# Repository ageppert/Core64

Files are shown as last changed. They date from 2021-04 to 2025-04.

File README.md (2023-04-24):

# Core64 and Core64c
Official Core64 and Core64c Interactive Core Memory Badge Kit Firmware and Documentation!

Weave your own 64 bits of core memory over the top of LEDs to interact with directly using a magnetic wand.



Purchase or get support: https://www.Core64.io

Follow this project's origin story at: https://hackaday.io/project/166155-core-64-interactive-core-memory-badge

This repository supports the Core64 and Core64c kits starting with the Beta Kit (Hardware Version 0.5.0).

See latest firmware release at https://github.com/ageppert/Core64/releases (pre-compiled firmware for Teensy 3.2 and Pico-based versions)

# Hardware Version History (latest on top)

Core64 V0.8 Pico-based Kit:

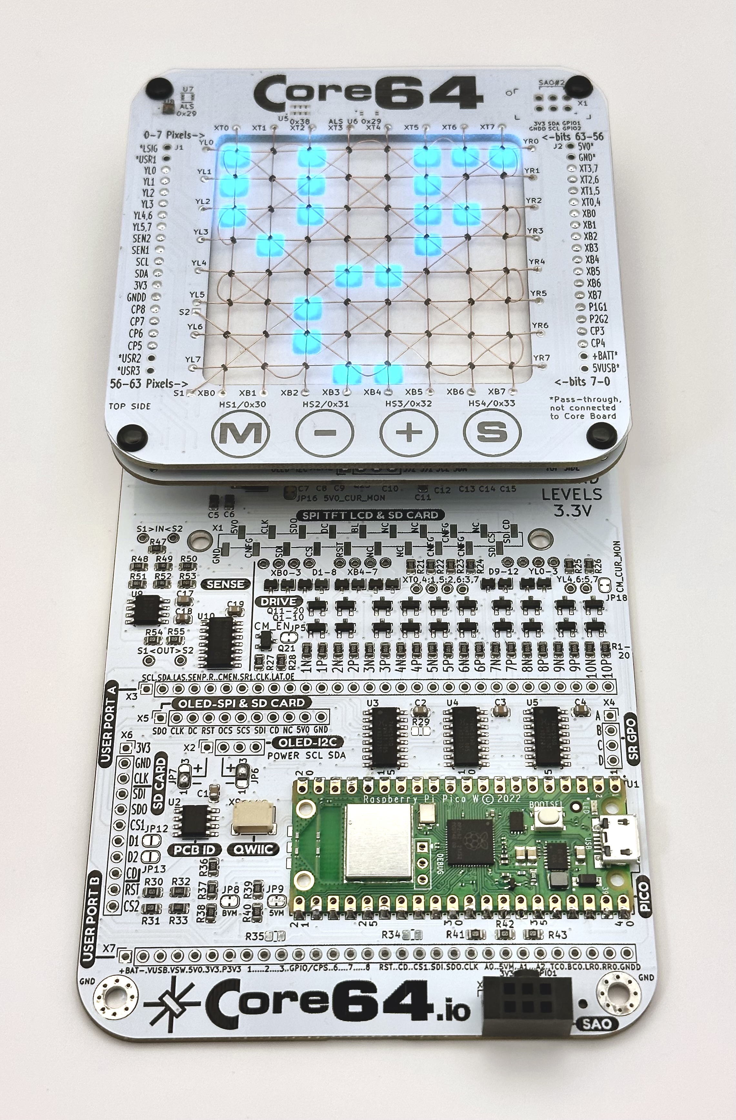
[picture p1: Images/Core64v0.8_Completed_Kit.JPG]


Core64c V0.4 Pico-based Kit:

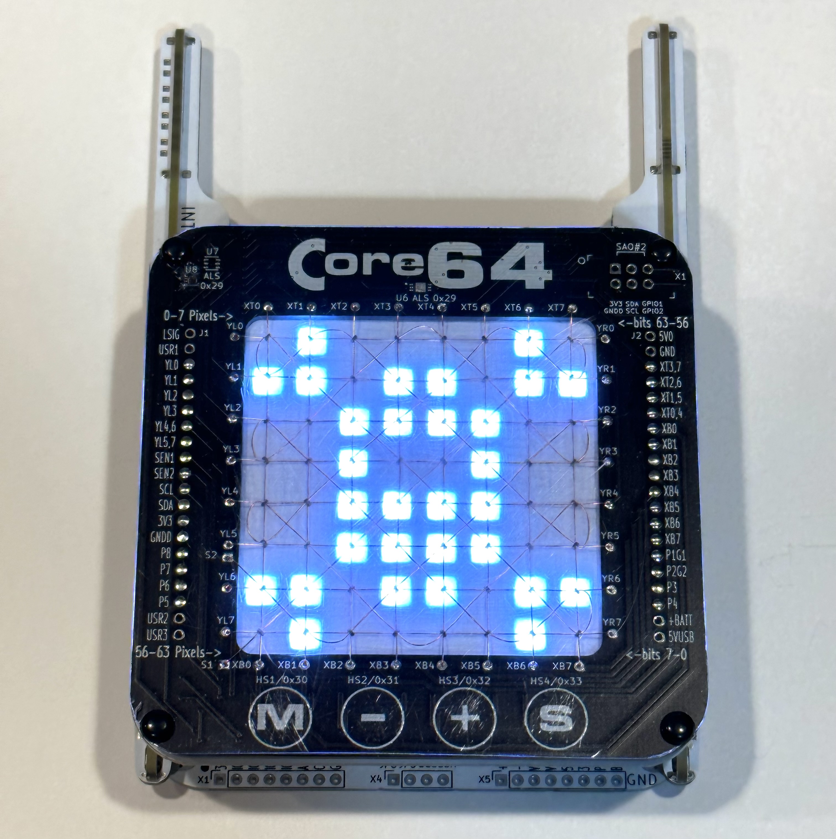
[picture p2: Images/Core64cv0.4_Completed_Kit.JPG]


Core64 V0.6 Pre-Production Teensy 3.2-based Kits. Associated Firmware Release https://github.com/ageppert/Core64/releases/tag/V0.6.3

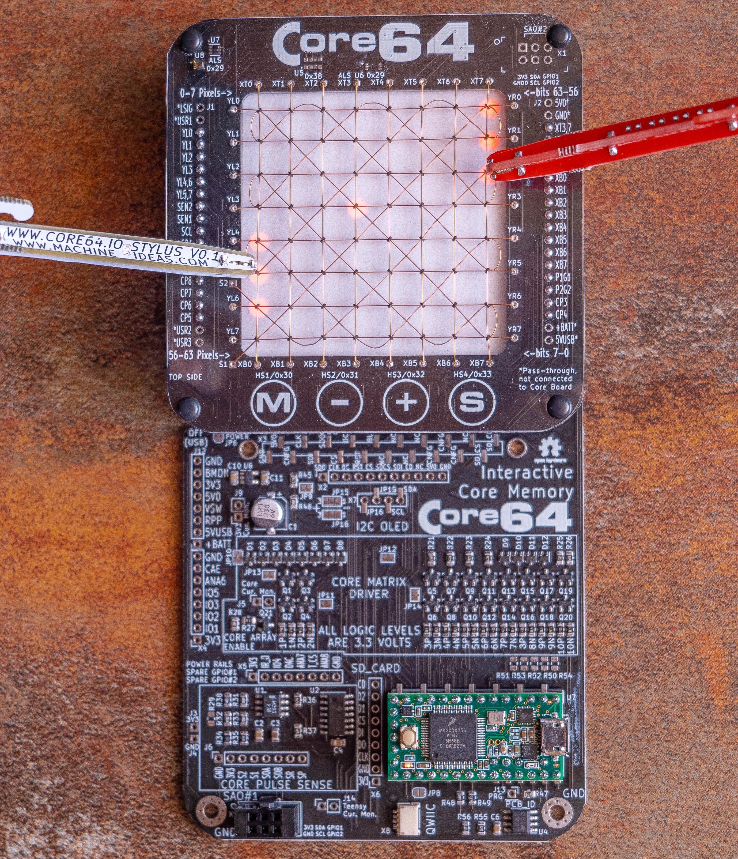
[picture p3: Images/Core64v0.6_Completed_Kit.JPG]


Core64 V0.5 Beta Test Kits Teensy 3.2-based. Associated Firmware Release https://github.com/ageppert/Core64/releases/tag/V0.5-Beta-Kit-Release-Demo

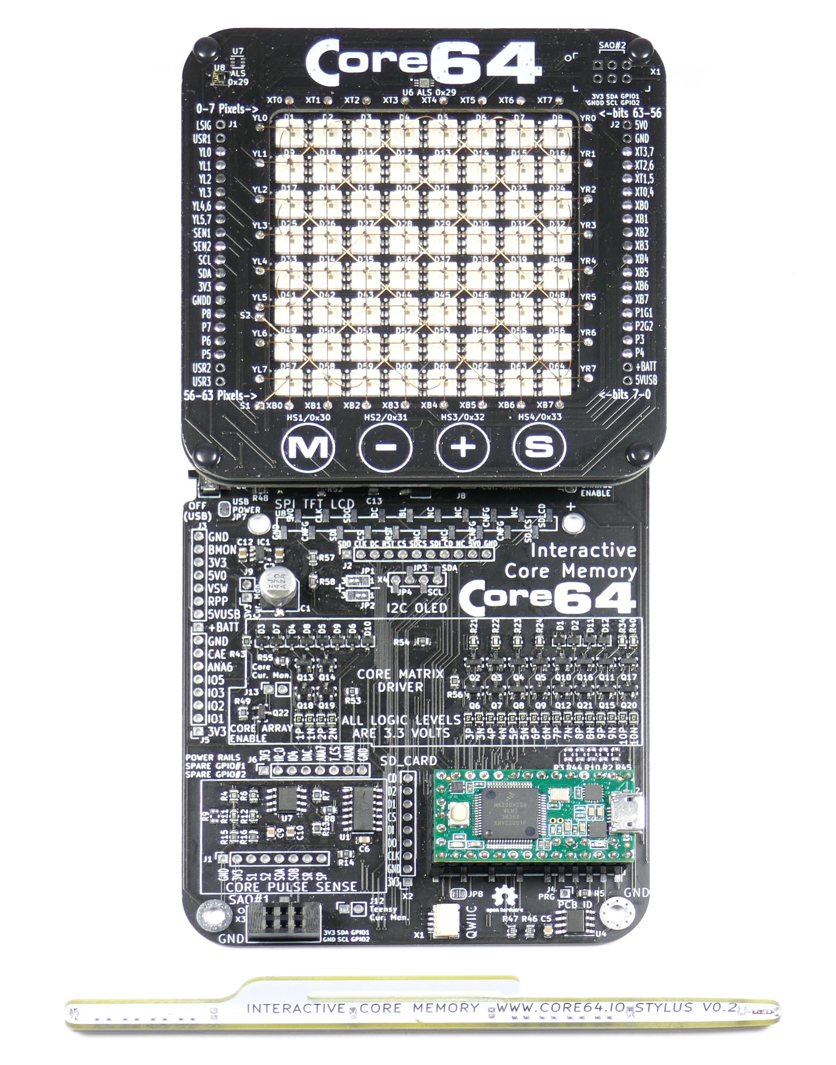
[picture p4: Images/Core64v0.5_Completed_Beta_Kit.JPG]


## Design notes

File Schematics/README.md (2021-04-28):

# Schematics

LB = Logic Board

CB = Core Board

LM = LED Matrix

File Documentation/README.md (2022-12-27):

# Core64 and Core64c
This directory contains all of the official Core64 and Core64c Interactive Core Memory Badge Kit Documentation.

You can view the files directly from your web browser, or download them to print out.

ASSEMBLY GUIDE: Start here. This covers the entire assembly process for the standard configuration of the kit. (This was previously hosted on GitBook, but the documents in this directory supersedes the information in Gitbook.)

FIRMWARE UPDATE GUIDE: After assembly is completed, you will be guided through the steps to install/update to the latest firmware.

QUICK START GUIDE: After the Core64 kit is working, you can jump to this guide to explore the basic operating modes.

TROUBLESHOOTING GUIDE: If the kit is not working correctly after the firmware has been updated, this guide will cover automated and manual troubleshooting techniques.

USER GUIDE: After you have the firmware installed and running, the User Guide will describe how to use the completed Core64 kit with all of it's standard functionality. There are also sections describing some simple upgrades you may want to perform, such as a different battery and display screens.

HACKER GUIDE: I know seeing "hacker" and "guide" together are the definition of an oxymoron... but this guide serves as a launching point for all sorts of hacking that you can do with this kit. The guide starts with all of the details about how the core memory and the standard features work. If covers the electronics in detail and touches on the concepts present in the firmware. It then offers up open-ended hacks and ideas that you can pursue. If you want to go deeper with the firmware, the PROGRAMMERS REFERENCE GUIDE is the place to go.

PROGRAMMERS REFERENCE GUIDE: If you want to modify or create your own firmware, this is the place to start! This guide starts with how to set up the development environment. It goes into detail regarding the architecture, file organization, and details of implementation.

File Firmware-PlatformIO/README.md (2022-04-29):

# Firmware Source Code
This sub-directory supports Core64 HWV0.4+ and Core64c HWV0.2+.

THis sub-directory supports firmware starting at FWV 0.7.0 using the PlatformIO environment in VSCode.

See the "Firmware" sub-directory for the older Arduino IDE firmware source code.

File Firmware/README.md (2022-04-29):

# Firmware Source Code
This sub-directory supports Core64 into HWV0.5.

This firmware (up to FWV0.6.3) is compatible with the Arduino IDE.

Firmware after FWV0.6.3, starting at FWV 0.7.0, moves to the PlatformIO environment in VSCode.

See the Firmware-PlatformIO sub-directory for that firmware source code.

Arduino project folder, sketches, libraries.

This firmware was used for development of Core64 V0.5 and beyond.

This firmware is also compatible with Core64c V0.2 and beyond.

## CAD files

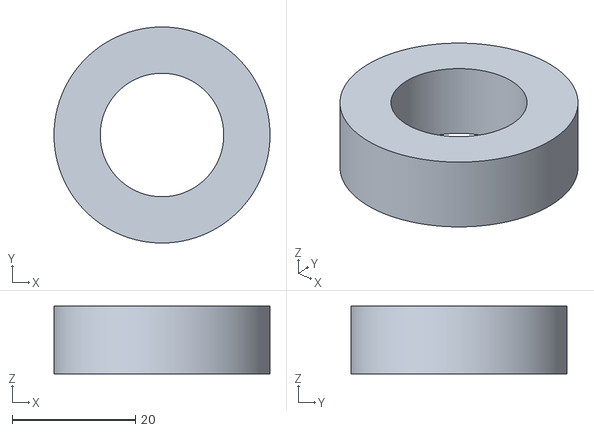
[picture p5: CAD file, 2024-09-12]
Mechanical/Core Memory Demo - Large Plastic Core.stl
35.0 x 35.0 x 11.0

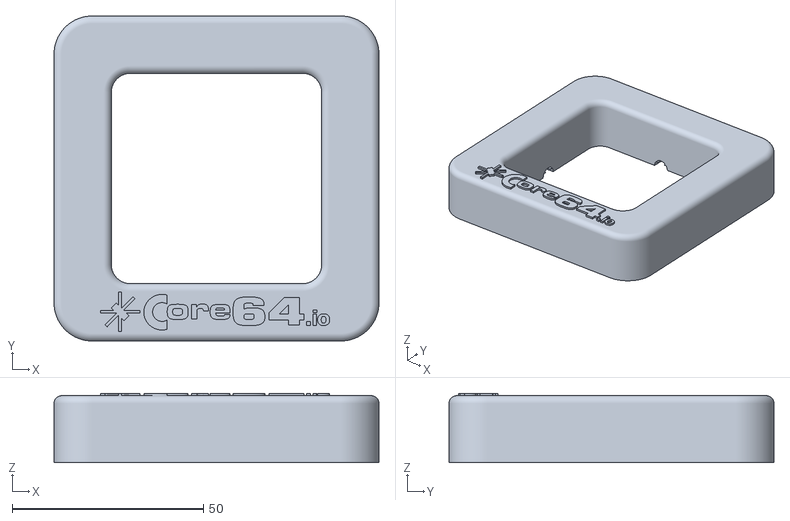
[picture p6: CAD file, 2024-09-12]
Mechanical/Core Memory Demo Frame - TOP.stl
85.0 x 85.0 x 18.1

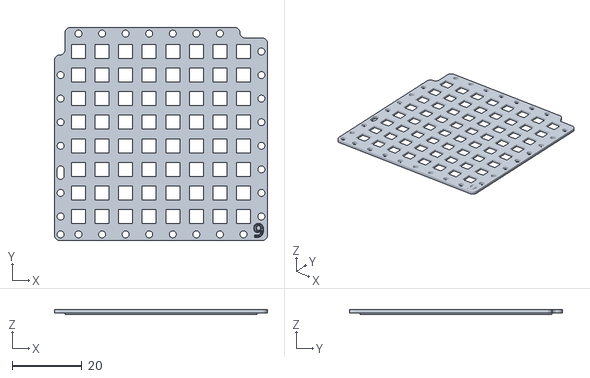
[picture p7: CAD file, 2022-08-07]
Mechanical/Diffuser Grid V0.9 Square 6.75mm centers.stl
61.0 x 61.0 x 1.40

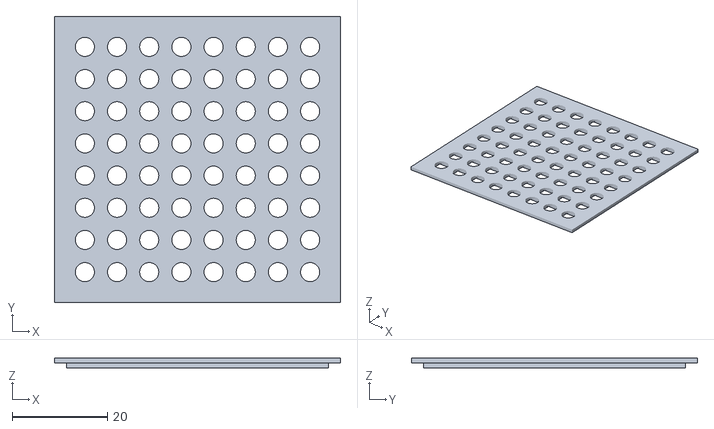
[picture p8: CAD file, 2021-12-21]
Mechanical/Diffuser Grid V0.2 Round 4mm Pixel Holes.stl
60.0 x 60.0 x 2.00

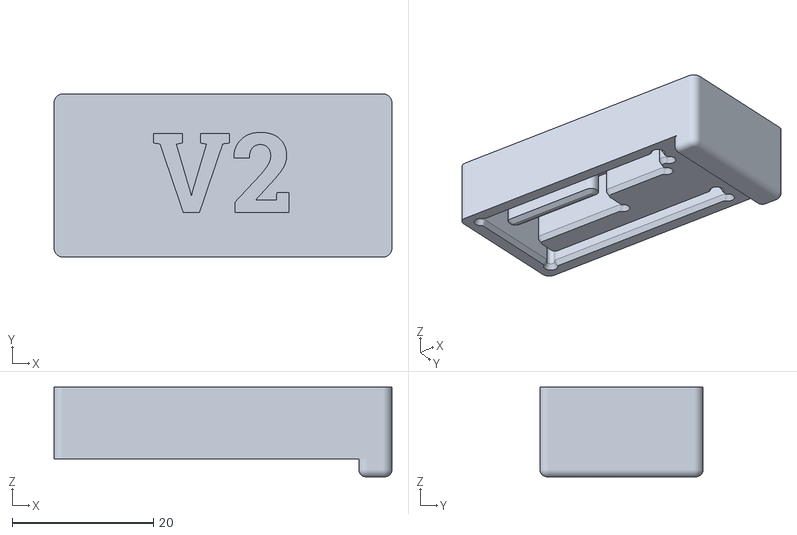
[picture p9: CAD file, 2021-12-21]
Mechanical/Alignment Jig Sockets Teensy3.2 on LB V0.5-0.6 (V2).stl
47.9 x 23.1 x 12.7

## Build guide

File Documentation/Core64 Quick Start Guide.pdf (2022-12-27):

Core Memory Interactive Kit - Core64 - Quick Start Guide | Firmware V0.7.22 | 2022-12-20 | Andy Geppert | www.Core64.io | 1

# Core64 Interactive Core Memory Kit Quick Start User Guide

- Power Switch (Selects battery power or USB power, if connected)
- Magnetic Stylus (used for all interaction with Core Memory Matrix and Soft Buttons)
- 8x8 Core Memory Array (top layer) and RGB LED Matrix (bottom layer)
- Magnetic hall sensor buttons: (M) (+) (-) (S) are Mode, Increase, Decrease, Select

Power ON starts in demo mode. Move through demo modes with (+) and (-) using the Magnetic Stylus.

Touch Menu (M) with the Magnetic Stylus to enter the dGAUSS top level menu. Touch again to exit to last mode. Touch sub-menu letter on LED Matrix to enter the sub-menus:
d = Demos (Scrolling text through core memory, color symbols without core detection)
G = Games (Snake, Pong)
A = Applications (Monochrome drawing, touch (S) with Magnetic Stylus to clear the screen)
U = Utilities (Flux Detector)
S = Special (Binary counting bits, Pixel sequence test, EEPROM test, rainbow color, toggle one bit, read/write one bit, read/write all bits, test hall sensors)
S = Settings (empty)

Sub-menu name will appear for 3 seconds and automatically move to the first and next items in the sub-menu list. In the sub-menu, move through available choices with (+) and (–) magnetic buttons. Select the desired mode displayed on the LED Matrix with the (S) magnetic button.

After 30 seconds of no user interaction, mode will return to the default demo mode. Except for drawing mode, which does not time-out.

Like all of the other documentation guides, this one assumes you are working with the latest firmware.

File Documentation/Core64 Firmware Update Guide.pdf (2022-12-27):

.io

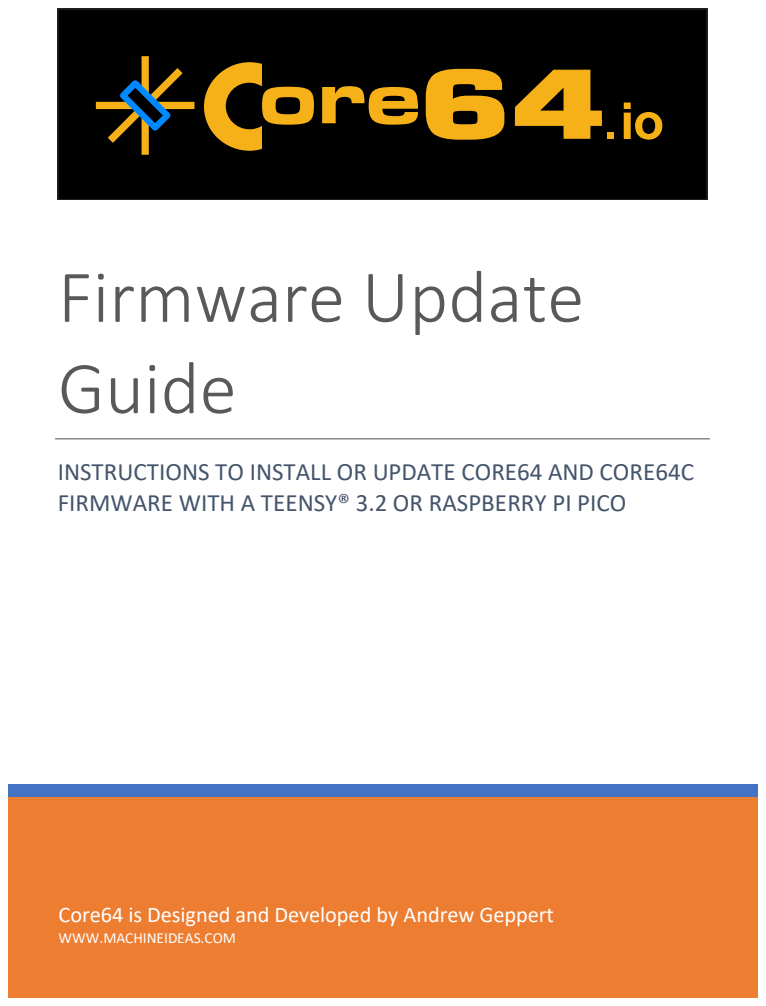
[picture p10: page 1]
Firmware Update Guide

INSTRUCTIONS TO INSTALL OR UPDATE CORE64 AND CORE64C
FIRMWARE WITH A TEENSY® 3.2 OR RASPBERRY PI PICO

Core64 is Designed and Developed by Andrew Geppert
WWW.MACHINEIDEAS.COM

Core64 Firmware Update Guide | www.Core64.io | 2

## 1. TABLE OF CONTENTS

The latest version of this and related Core64 guides are located at: https://github.com/ageppert/Core64/tree/master/Documentation

## 2. VERSION HISTORY OF THIS GUIDE

Revision | Description | Author | Date
A | First draft. | Andy Geppert | 2022-12-23

## 3. IMPORTANT CAUTIONS AND WARNINGS

Beware the ESD monster!

Sometimes the term “Core64” might refer generally to “Core64c” which is the compact version. Core64 is specifically the larger or full-size version.

Do not place the Core64 circuit boards directly on a metal surface.

⚠ These caution symbols point out important things to help ensure your assembly goes smoothly!

## 4. INTRODUCTION

This guide attempts to make the firmware update as simple as possible. If you’d like more detail so you can modify or create your own firmware for Core64, check out the Core64 Programmers Reference Guide.

Kits with the Raspberry Pi Pico (all Core64c kits, and Core64 V0.7+ kits) are not pre-programmed with firmware. However, the Pico is very easy to update because it does not need a special firmware loader. To program or update the Pico, simply drag-n-drop the firmware.uf2 file onto it when it is mounted on the computer’s desktop. For details, see section 5. Pico: Firmware Update.

The Teensy® 3.2 (used in early Core64 kits) is pre-programmed with firmware which will get you started with some basic functionality. Updating and programming the Teensy® requires a special firmware loader. A specific firmware upload tool is required for programming the Teensy® 3.2. It is developed and supported by PJRC, who are the makers of the Teensy® series of microcontroller boards. To update the Teensy® 3.2, you’ll need the Teensy® Loader. Details for installing the software and updating the Teensy® 3.2 are in Section 6. Teensy®: Firmware Update.

Please use the latest firmware. Some limited notes about older versions of the firmware are listed in the appendix, but those versions are incomplete and unsupported. And they aren’t as much fun as the latest firmware.

This guide assumes you have the Teensy® or Pico microcontroller installed on the Core64 Logic Board. They can also be programmed as a standalone device.

The next sections describe all the steps in detail. At the time of this writing, the instructions only cover Windows and Mac operating systems. If you are running Linux, I assume you can figure out how to adapt these instructions to your OS. And there are a lot of resources on the web to supplement these instructions if you get stuck.

## 5. PICO: FIRMWARE UPDATE

The firmware update process is very simple for the Pico. No installers are needed.

Step 1: Connect USB Cable
Connect the Pico to your computer with the MicroUSB data cable.

The Pico should now be mounted on the desktop as a USB mass storage device. If it does not show up, unplug it, then hold down the button on the Pico and plug in the USB cable, then release the button. This forces it into bootloader mode.

Step 2: Download Firmware
Download the latest firmware from https://github.com/ageppert/Core64/releases
Expand Assets and click on the “Core64_Pico_x.y.z_firmware.uf2” file to save it to your Downloads folder.

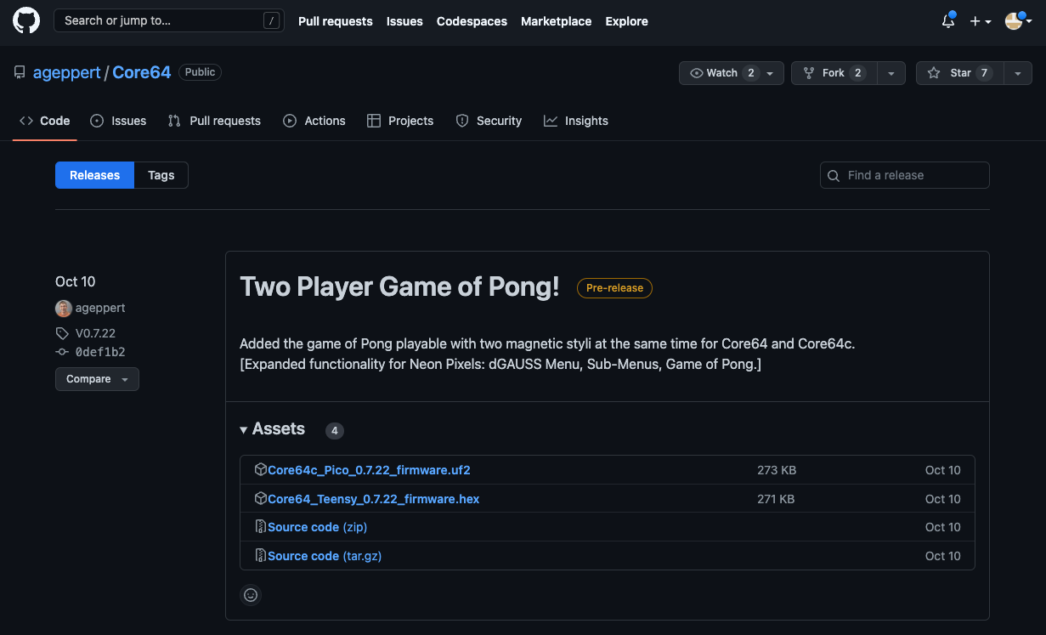
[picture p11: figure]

Step 3: Install the Firmware
Drag and drop the “Core64_Pico_x.y.z_firmware.uf2” file to copy it into the Pico mass storage device.

The Pico will reboot and run the firmware. You will see text scrolling on the LED Array. If it does not automatically reboot, unplug the USB cable, and plug it back it.

That’s it.

## 6. TEENSY®: FIRMWARE UPDATE

The firmware update process is a tiny bit more involved for the Teensy® 3.2-based Core64 kits because it requires the Teensy® Loader.

Step 1: Download Firmware
Download the latest firmware from https://github.com/ageppert/Core64/releases
Expand Assets and click on the “Core64_Teensy_x.y.z_firmware.hex” file to save it to your Downloads folder.

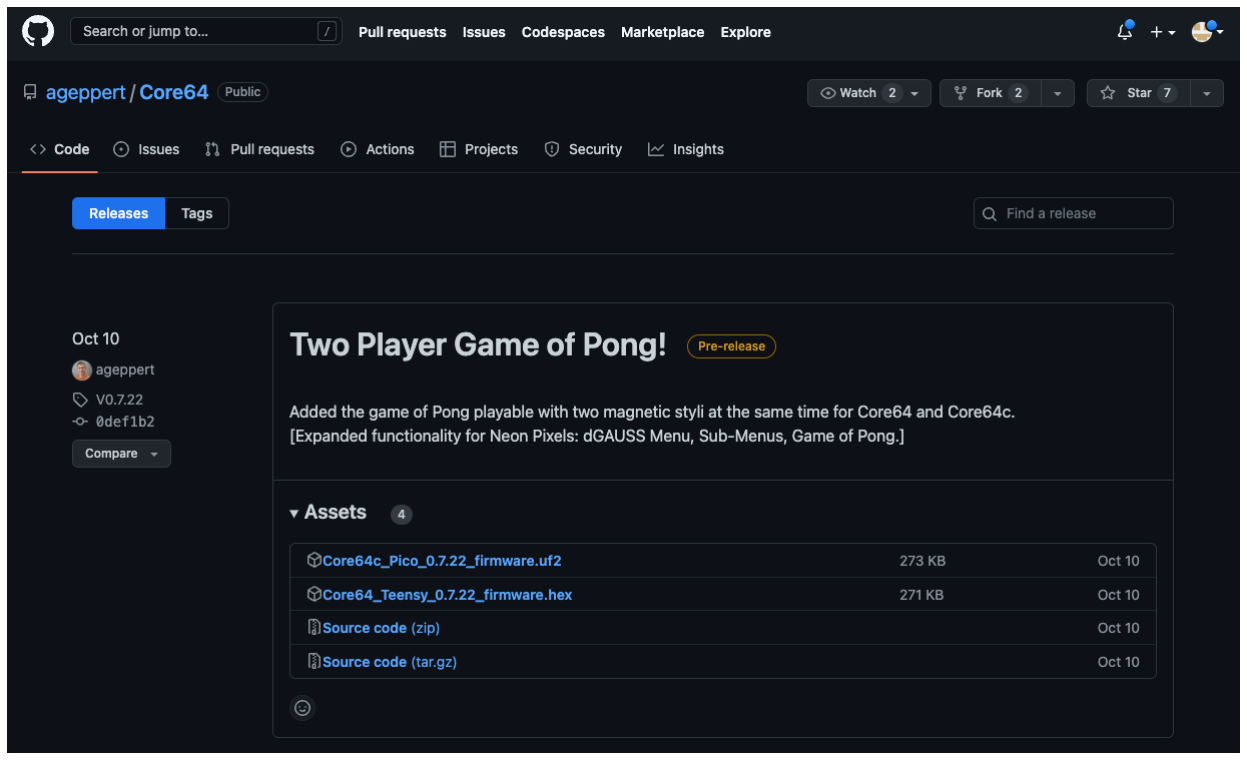
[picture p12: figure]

Step 2: Get the Teensy® Loader
Download/Install the standalone Teensy® Loader from https://www.pjrc.com/Teensy®/loader.html
Read the instructions for use with your OS on that page as well.
Run the Teensy® Loader Application.
If you already have Teensy® Loader installed with the Arduino IDE or VS Code and PlatformIO, you can start the Teensy® Loader from within those IDEs.
Step 3: Connect USB Cable
Connect the Teensy® 3.2 to your computer with the MicroUSB data cable.
Step 3: Install the Firmware
Drag and drop the “Core64_Pico_x.y.z_firmware.hex” file onto the Teensy® Loader window.
Press the button on the Teensy® 3.2 and the Teensy® Loader should recognize it and program it with the firmware. The Teensy® should reboot and text should begin scrolling on the Core64 LED Array.

That’s it.

## 7. TROUBLESHOOTING FIRMWARE UPLOADS

The first thing to check is the cable. Make sure you have a good USB cable, with data wires, and good connections to the ports at each end. The USB cable included in the Core64 Kit meets these criteria. Still, you should verify the cable is working with data by testing it with other known working devices to be sure.

Try a different computer if the USB cable is known to be good, but the microcontroller isn’t connecting fully to the computer and showing up as a serial device.

The MicroUSB cable connects in one direction to the Pico or Teensy®. Careful – it only inserts in one orientation.

The MicroUSB cable must be a DATA cable. It basically impossible to tell if a USB cable is power only or power+data by looking at it from the outside. You have to test it to find out.

The built-in LED on the microcontroller board should be blinking, which indicates it is getting power from the USB cable.

The Core64 power switch can be either On or Off. The microcontroller will be powered and connected via the USB cable, so battery power is not required. But the batteries can be installed.

The next step is to make sure the microcontroller board is connecting to the computer and showing up correctly – usually that means as a USB Serial connection, and/or USB Storage Device.

Check your system USB connections to make sure the microcontroller is showing up as a connected USB device.
- Mac : Apple icon, About This Mac, System Report
- Windows: Windows Key, search for and run Device Manager

The Pico should show up on your desktop as a mass storage device.

The Teensy® should show up as a serial port device. It won’t show up on your desktop.

You will likely find similar advice if you search web for these kinds of connection issues.

You may also find support here: https://discord.gg/nPcTNNfMmd

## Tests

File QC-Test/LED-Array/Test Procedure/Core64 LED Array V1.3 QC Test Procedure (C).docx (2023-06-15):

Core64 LED Array V1.3

QC Test Procedure

Doc Version | Description | Date | Author
A | First draft outlined. Using WS2813C addressable LEDs. | 2023-05-09 | Andy Geppert
B | Move good/bad LEDs pics to Manufacturing Instructions. Add Appendix A: Test Firmware Description. | 2023-05-22 | Andy Geppert
C | Clarify three test connection points on PCB. | 2023-06-15 | Andy Geppert

# Introduction

Test procedure to ensure 100% functional LED Array assemblies. Includes illustrations of good and bad LEDs which have been encountered during multiple production runs. This test procedure applies to every LED Array which is assembled.

# Set-up

Functional test requires using an Arduino-compatible development board running test firmware provided from: https://github.com/ageppert/Core64/tree/master/QC-Test/LED-Array

Pre-built hex files for specific Arduino models is included and the firmware may be compiled for other Arduino-compatible boards with the Arduino IDE available at https://www.arduino.cc

Three connections are required between the Arduino board and the LED Array:

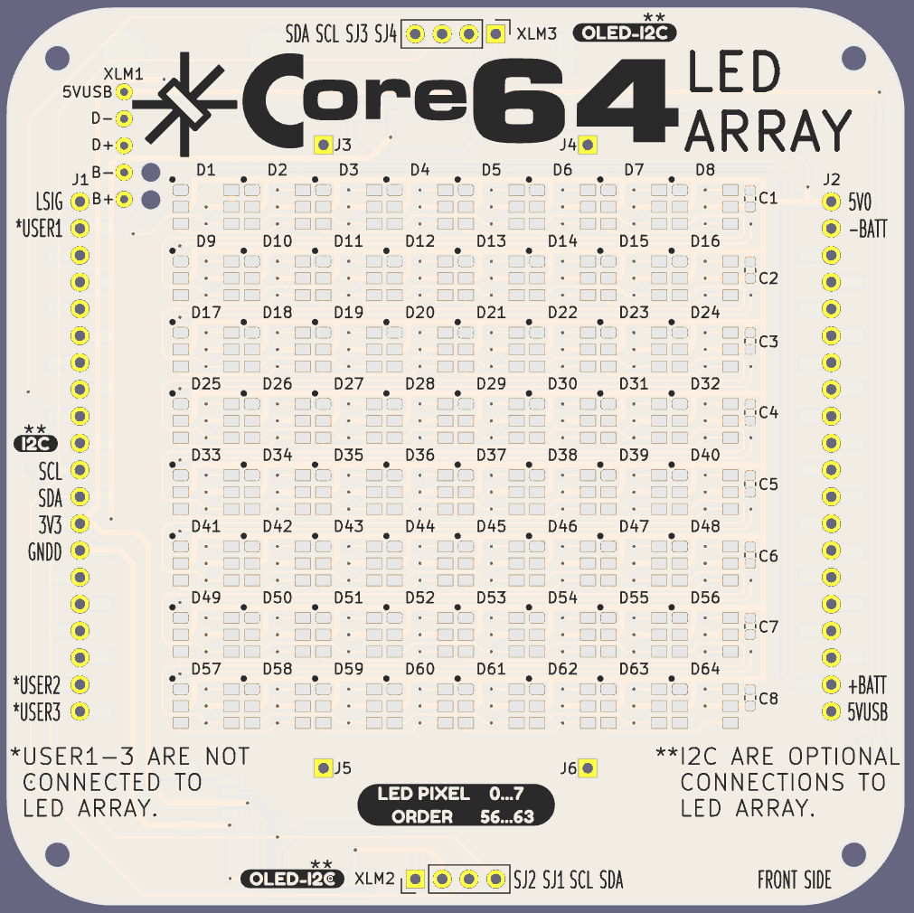
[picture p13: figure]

LED Signal LSIG on PCB

+5VDC is 5V0 on PCB

Ground is -BATT on PCB

A test fixture may be constructed with 5 pogo pins. Four pins distributed to each corner of the header rows on the LED Array, and 5th pin as Ground, second down from the upper right. The two rows of headers pins on the left and right edge of the LED array are all on a 0.1 inch grid for compatibility with protoboard.

# Test Procedure

1. Power to Arduino Board is disconnected.
2. Connect LED Array to Arduino Board.
3. Power on Arduino Board.
4. Observe all LEDs are illuminated RED at even brightness for a short period of time.
5. Observe all LEDs are illuminated GREEN at even brightness for a short period of time.
6. Observe all LEDs are illuminated BLUE at even brightness for a short period of time.
7. Observe all LEDs are illuminated WHITE at even brightness for a short period of time.
8. For one unit of every 10 that are manufactured, allow the light cycle to run for 30 minutes and recheck steps 4 through 7.
9. For the remaining 9 units, the test may conclude after step 7.
10. Power off the Arduino Board.
11. Disconnect the LED Array from the Arduino Board.
12. Place a black sharpie mark on the top of any LED which fails any of the color checks.
13. For each LED Array, record the number of failed LEDs in the first test. Record the number of failed LEDs in subsequent tests after the rework procedure is completed.

# Rework Procedure

1. Using a hot plate, heat the bottom side of the LED Array board to 230°C [TODO: double check that temp].
2. Remove failed LEDs.
3. Installed replacement LEDs with a small amount of flux pre-applied to the LED terminals.
4. Let the board cool slowly.
5. Re-test the board.

# Appendix A: Test Firmware Description

Red LEDs 1.5s on.

Green LEDs 1.5s on.

Blue LEDs 1.5s on.

All LEDS 1.5s on.

Repeat.

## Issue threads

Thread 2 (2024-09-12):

Core16_64_64c_Pico_0.8.10.uf2: LED test blinking works Raspberry Pi Pico, not on Pico W

mychrisdangelo, 2024-09-12:
Core16_64_64c_Pico_0.8.10.uf2: LED test blinking works Raspberry Pi Pico, not on Pico W

I'm working my way through the project now. Thanks for putting this all together.

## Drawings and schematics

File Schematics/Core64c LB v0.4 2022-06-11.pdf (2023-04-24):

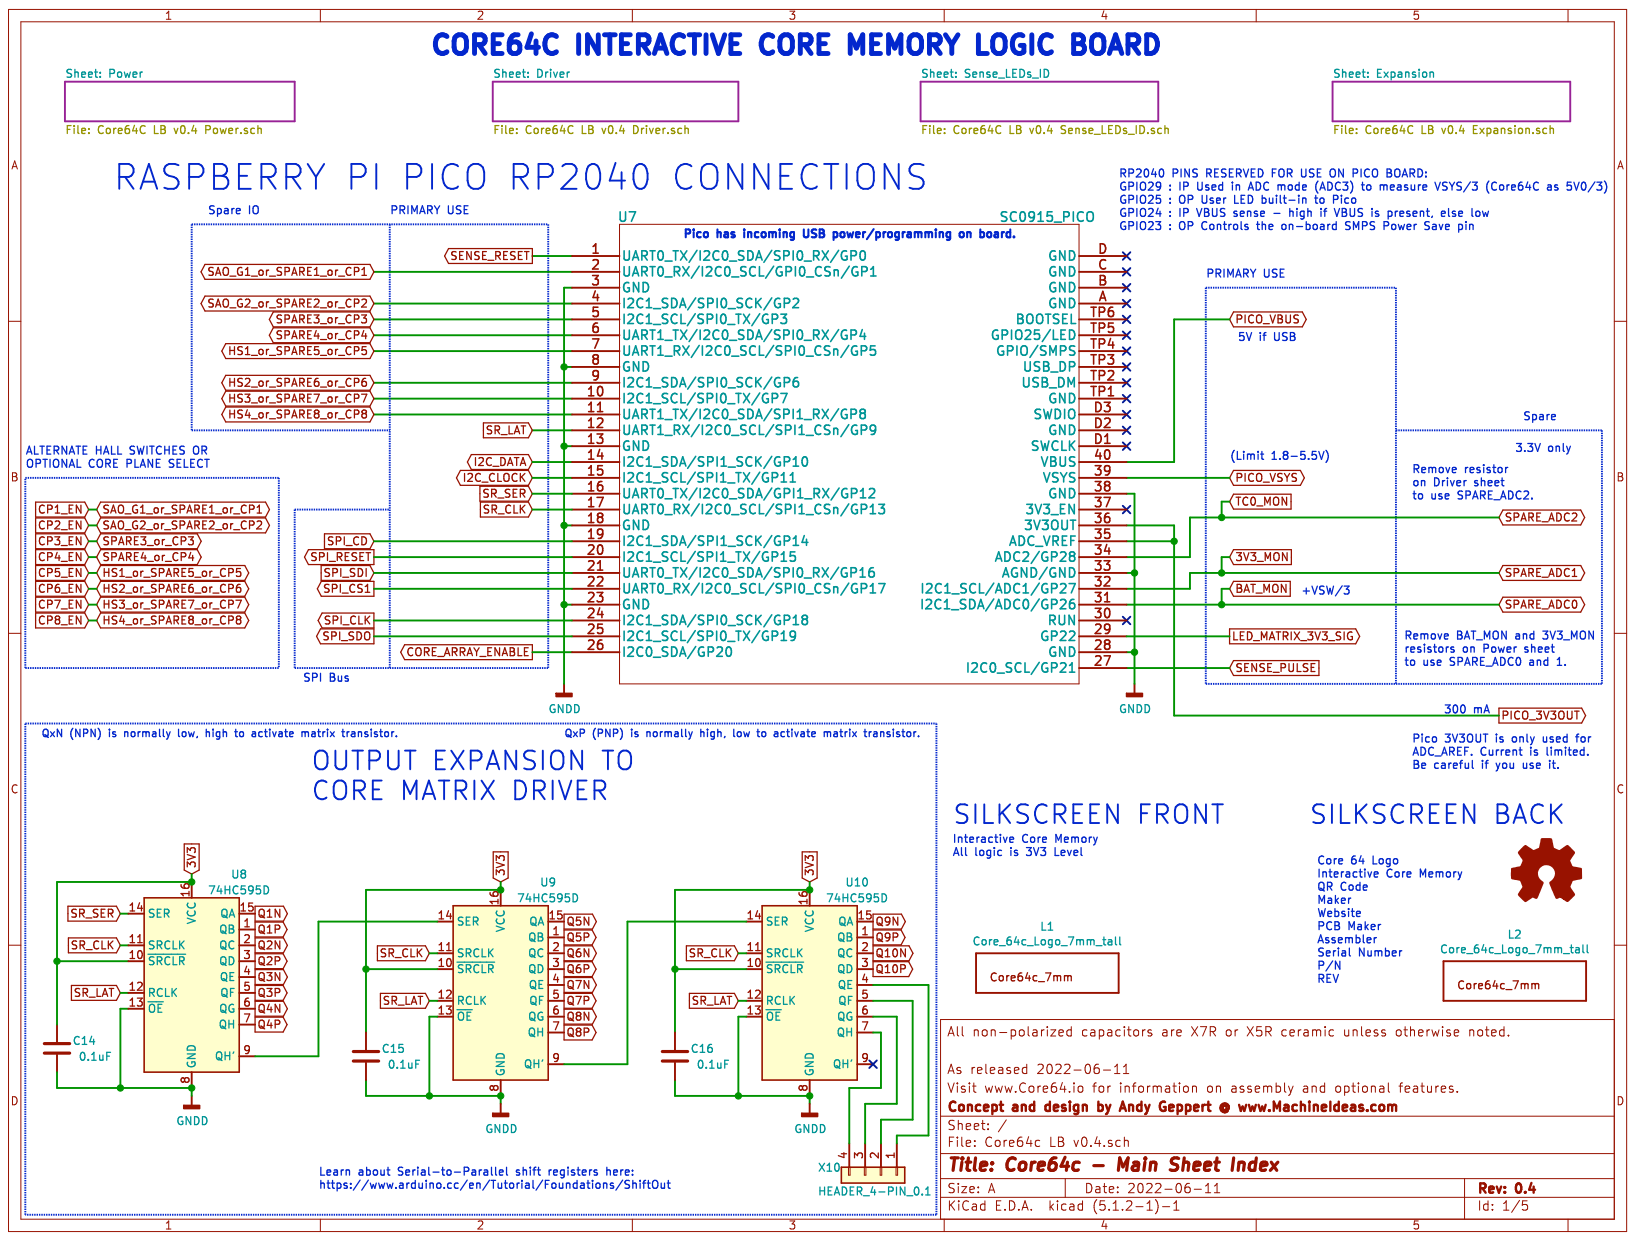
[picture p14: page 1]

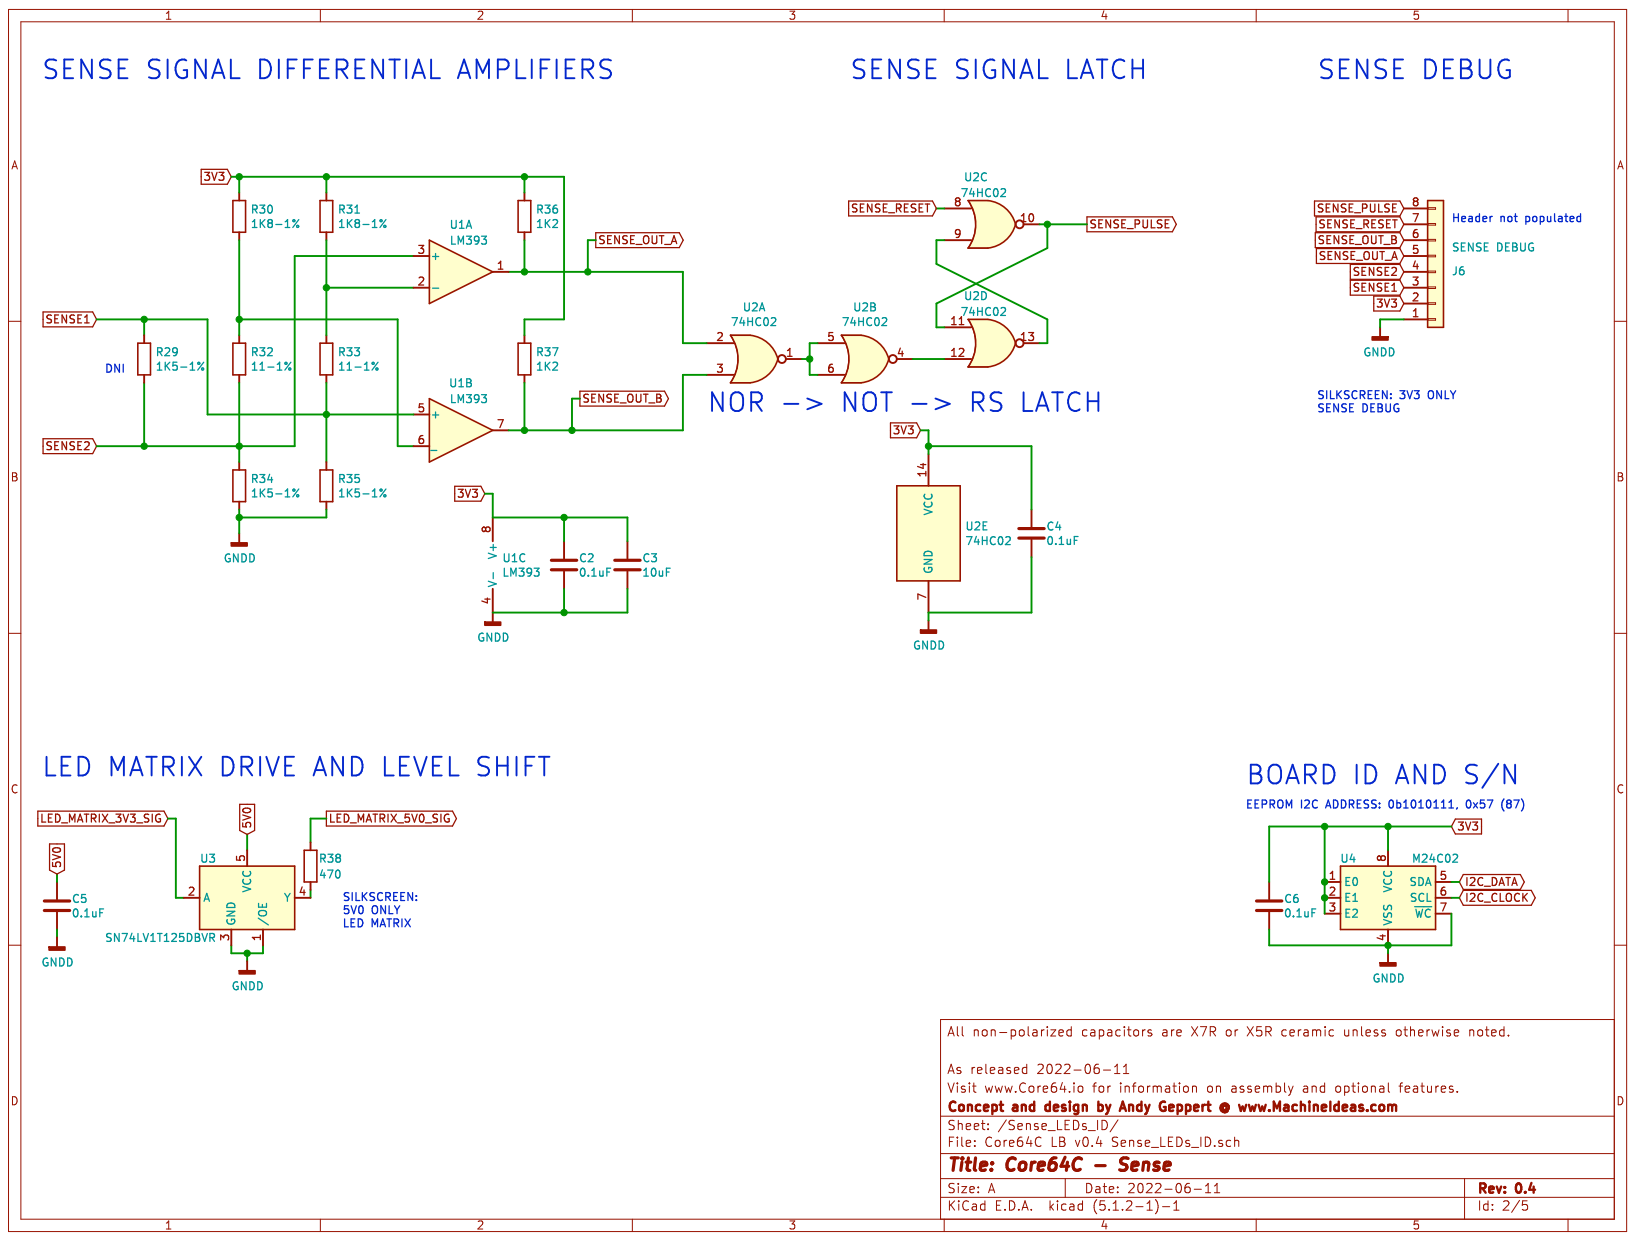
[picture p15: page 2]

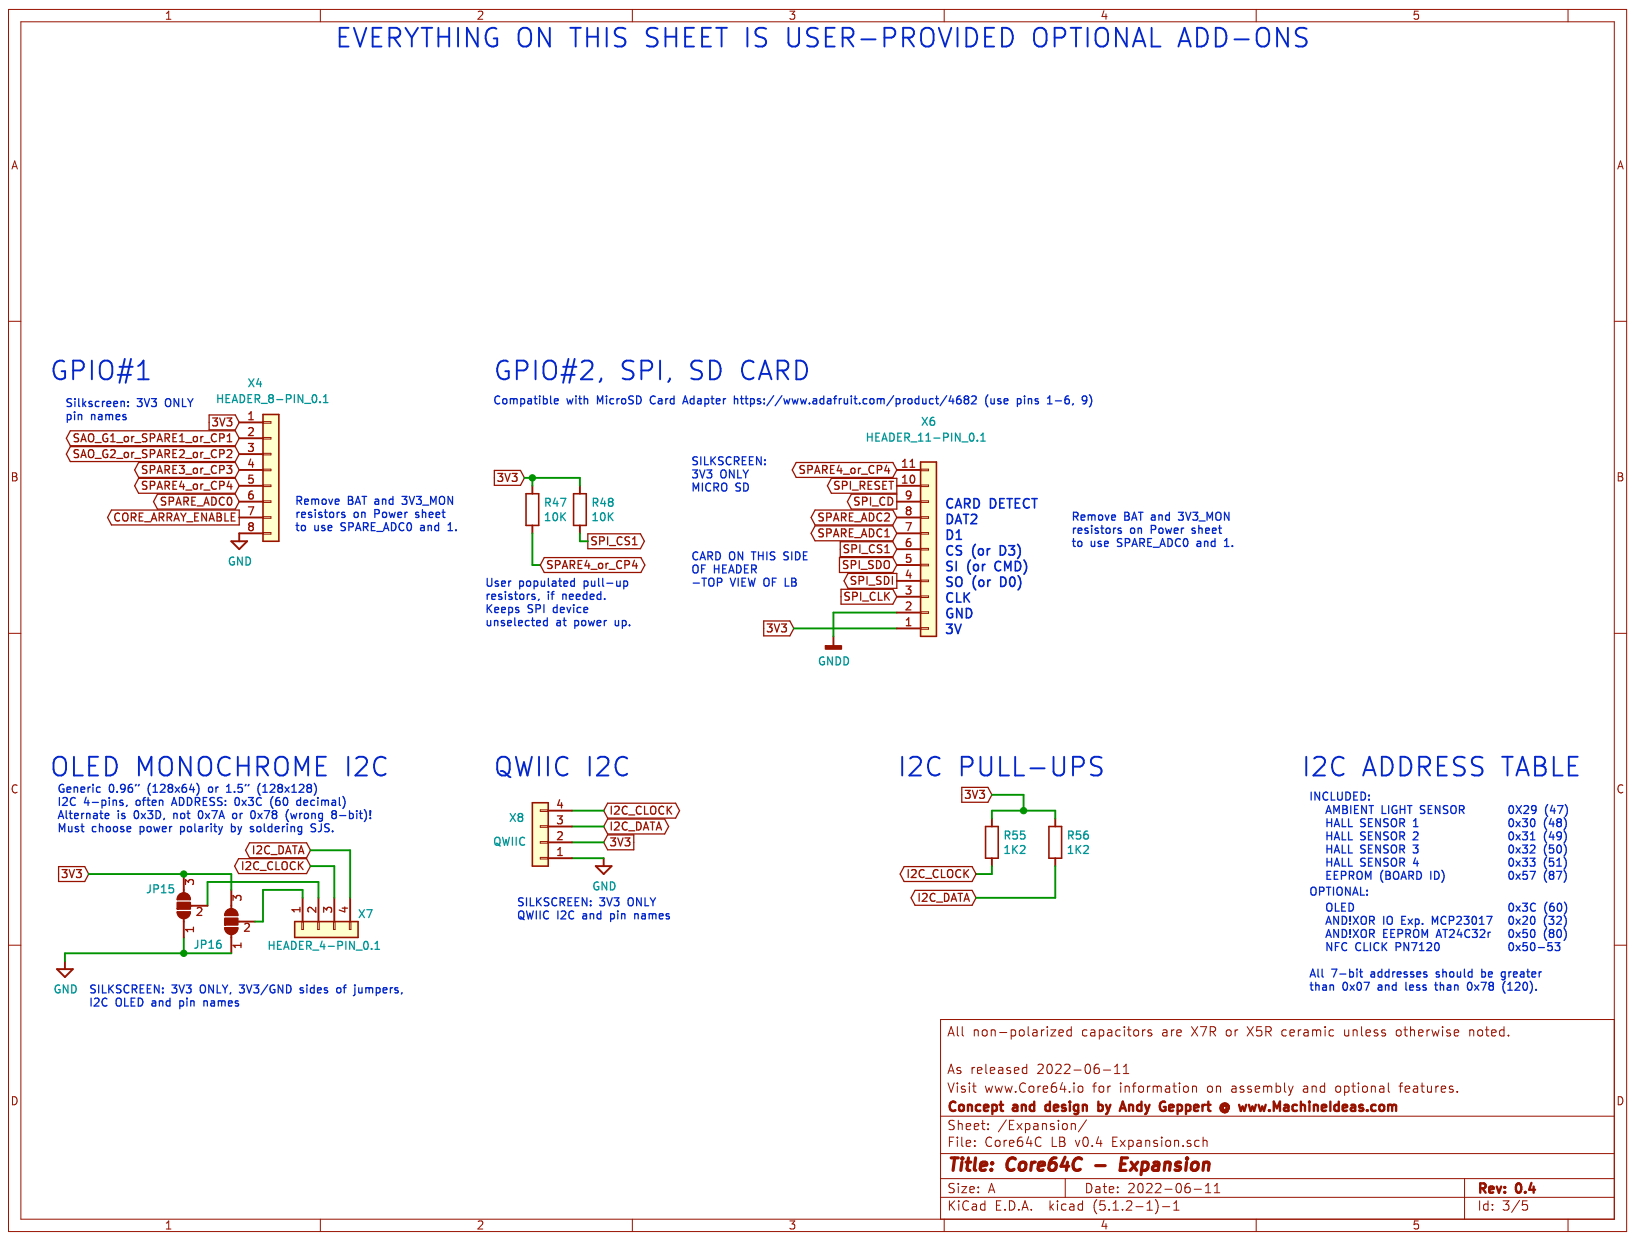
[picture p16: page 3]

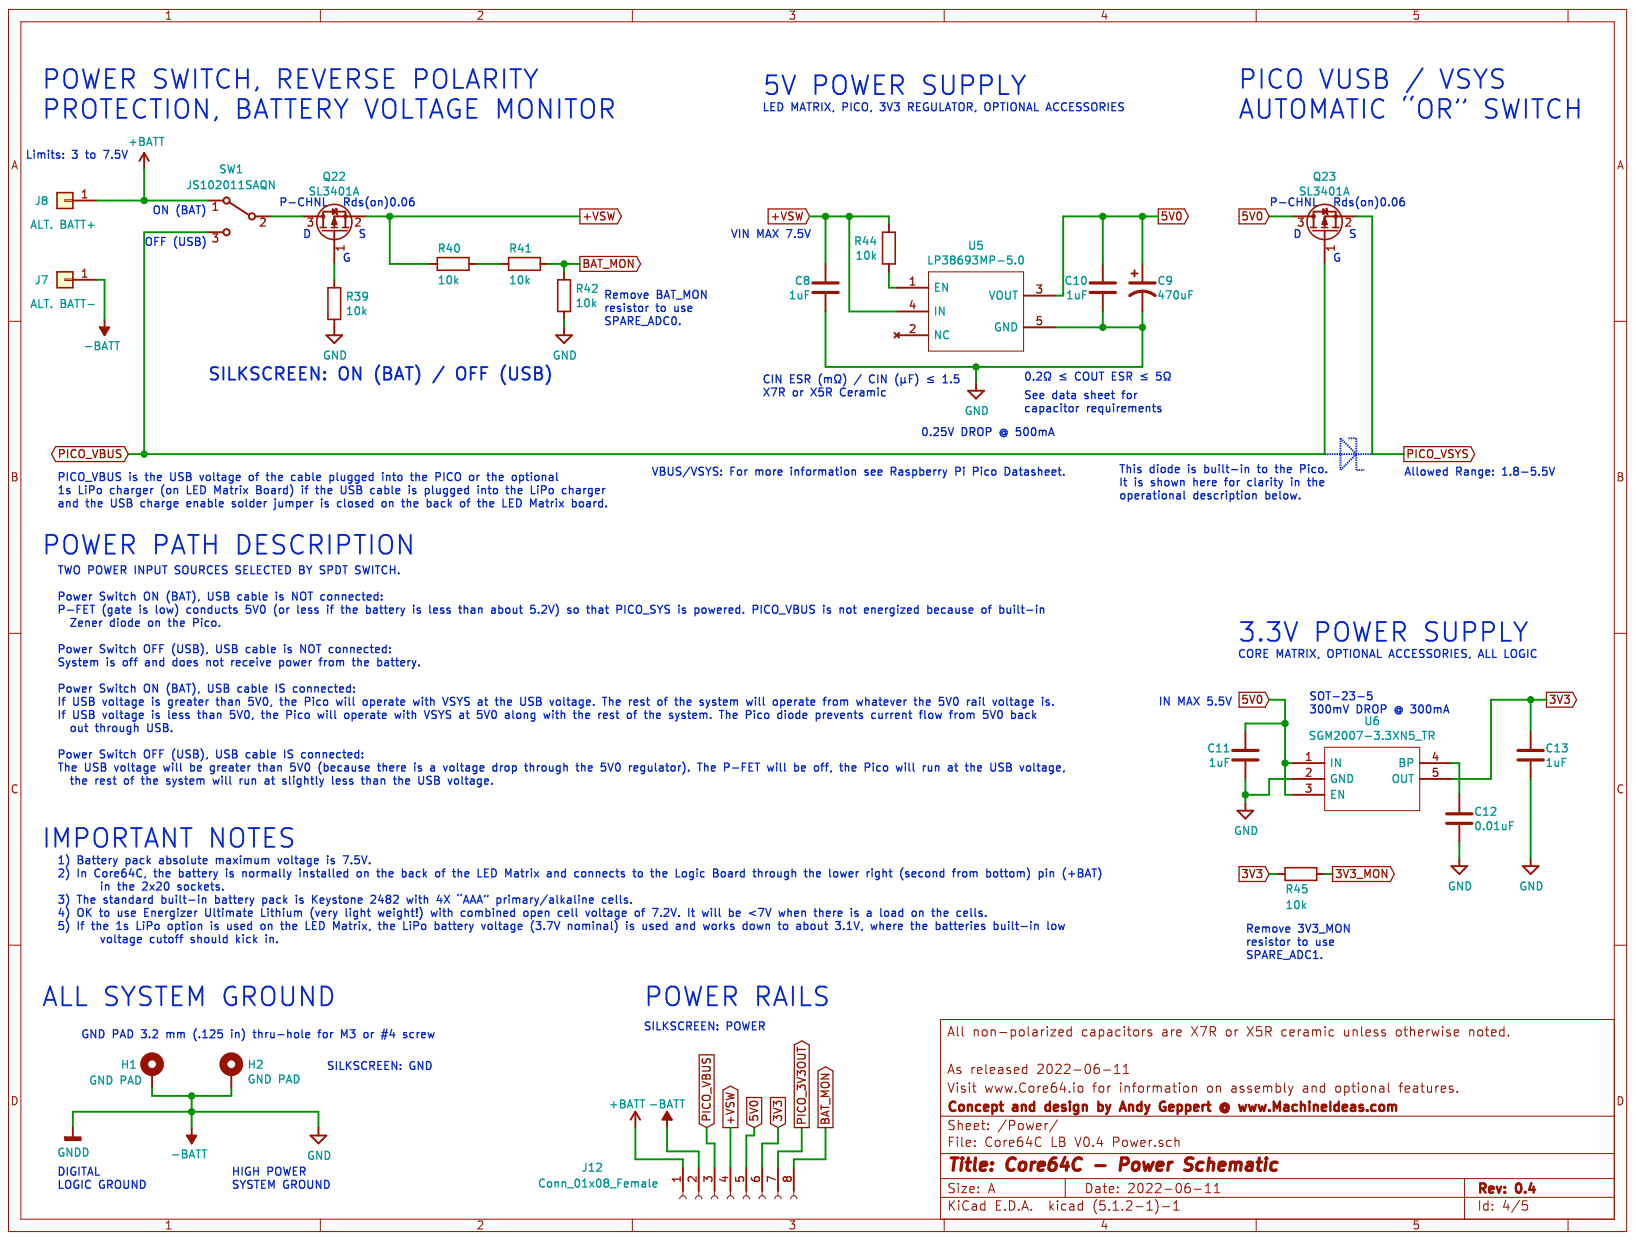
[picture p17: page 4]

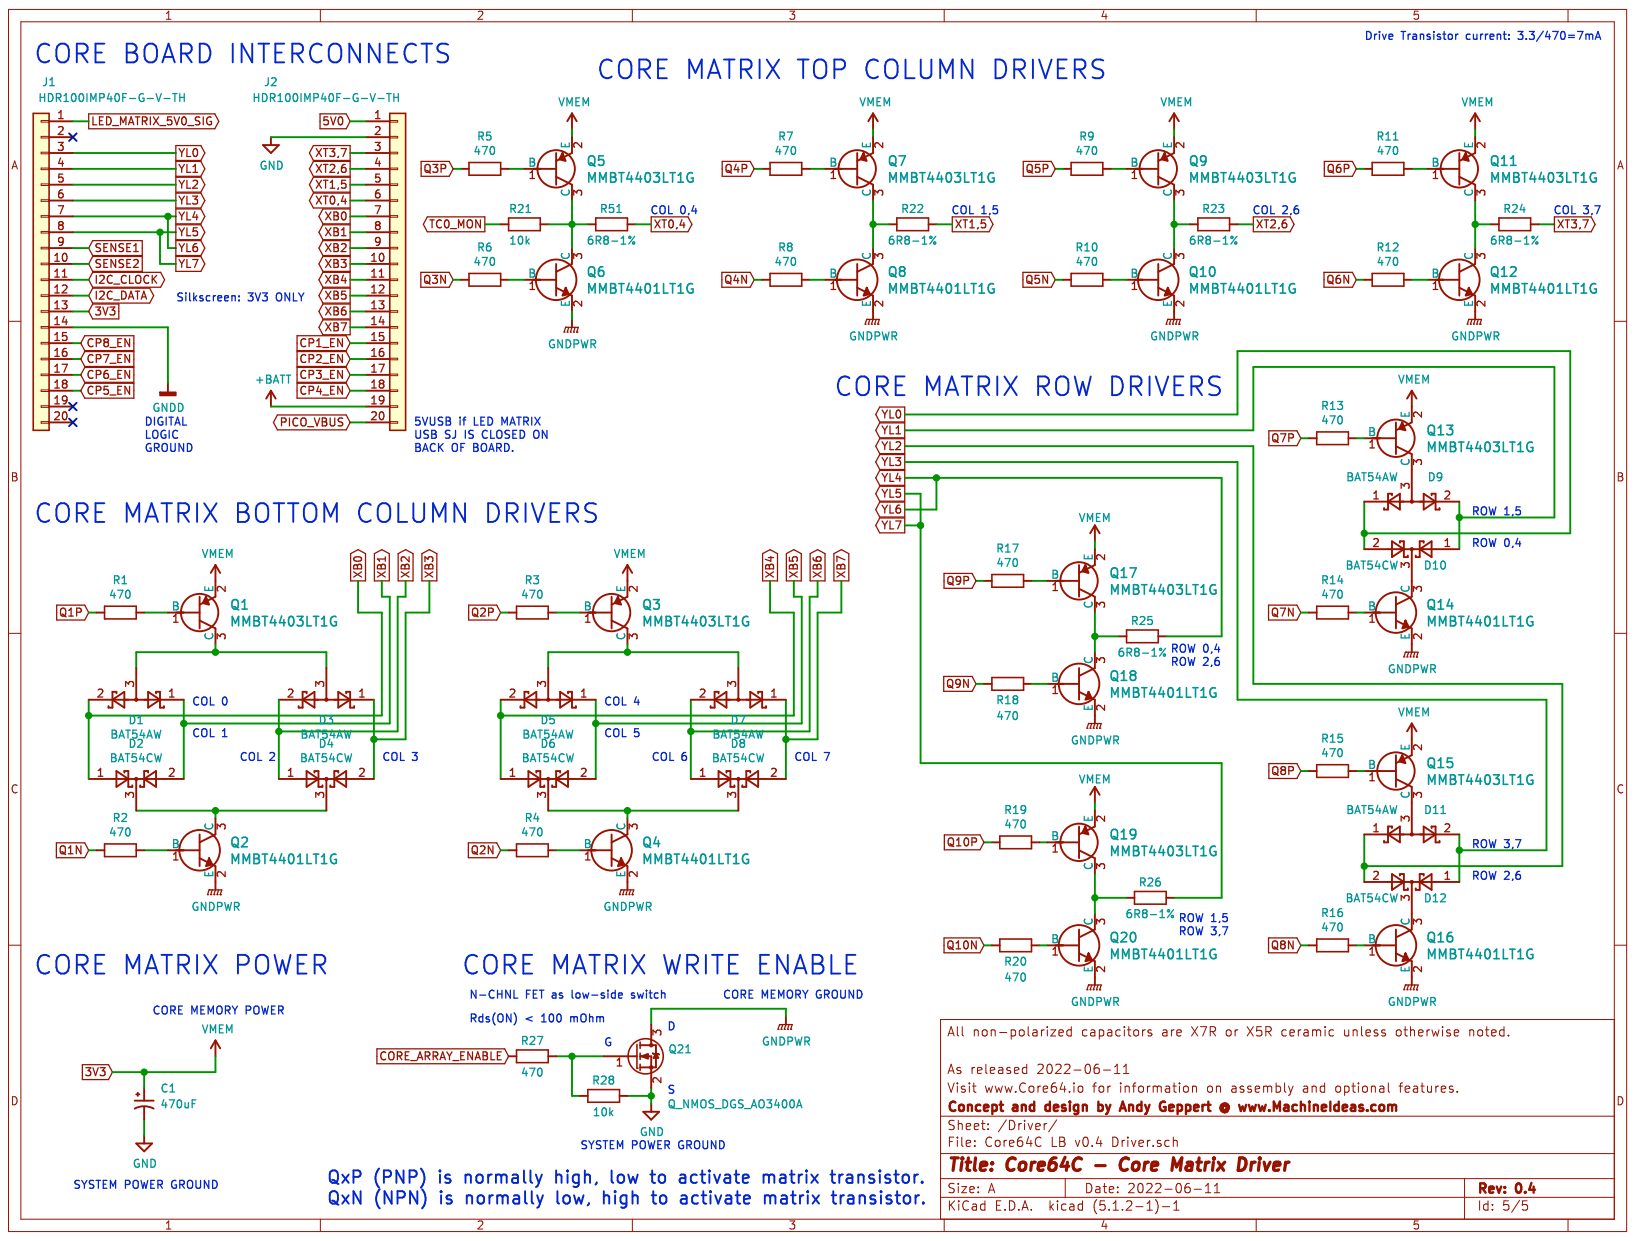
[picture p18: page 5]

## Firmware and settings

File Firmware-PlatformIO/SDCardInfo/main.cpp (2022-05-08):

#include <Arduino.h>  // Required in order to build in PlatformIO

/****************************************************************************************************************************
  CardInfo.ino
  
  For all RP2040 boads using Arduimo-mbed or arduino-pico core
  
  RP2040_SD is a library enable the usage of SD on RP2040-based boards
  
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
  Based on and modified from  Arduino SdFat Library (https://github.com/arduino/Arduino)
  
  (C) Copyright 2009 by William Greiman
  (C) Copyright 2010 SparkFun Electronics
  (C) Copyright 2021 by Khoi Hoang
  
  Built by Khoi Hoang https://github.com/khoih-prog/RP2040_SD
  Licensed under GPL-3.0 license
 *****************************************************************************************************************************/
/*
  SD card connection
  This example shows how to read and write data to and from an SD card file
  The circuit:
   SD card attached to SPI bus as follows:
   // Arduino-pico core
   ** MISO - pin 16
   ** MOSI - pin 19
   ** CS   - pin 17
   ** SCK  - pin 18
   // Arduino-mbed core
   ** MISO - pin 4
   ** MOSI - pin 3
   ** CS   - pin 5
   ** SCK  - pin 2
*/


#if !defined(ARDUINO_ARCH_RP2040)
  #error For RP2040 only
#endif

#if defined(ARDUINO_ARCH_MBED)
  
  #define PIN_SD_MOSI       PIN_SPI_MOSI
  #define PIN_SD_MISO       PIN_SPI_MISO
  #define PIN_SD_SCK        PIN_SPI_SCK
  #define PIN_SD_SS         PIN_SPI_SS

#else

  #define PIN_SD_MOSI       PIN_SPI0_MOSI
  #define PIN_SD_MISO       PIN_SPI0_MISO
  #define PIN_SD_SCK        PIN_SPI0_SCK
  #define PIN_SD_SS         PIN_SPI0_SS
  
#endif

#define _RP2040_SD_LOGLEVEL_       1

#include <SPI.h>
#include <RP2040_SD.h>

// set up variables using the SD utility library functions:
Sd2Card card;
SdVolume volume;
File root;

const int chipSelect = PIN_SD_SS;

void printDirectory(File dir, int numTabs) 
{
  while (true) 
  {
    File entry =  dir.openNextFile();

    if (! entry) 
    {
      // no more files
      break;
    }
    
    for (uint8_t i = 0; i < numTabs; i++) 
    {
      Serial.print('\t');
    }
    
    Serial.print(entry.name());
    
    if (entry.isDirectory()) 
    {
      Serial.println("/");
      printDirectory(entry, numTabs + 1);
    } 
    else 
    {
      // files have sizes, directories do not
      Serial.print("\t\t");
      Serial.println(entry.size(), DEC);
    }
    
    entry.close();
  }
}

void setup() 
{
  // Open serial communications and wait for port to open:
  Serial.begin(115200);
  while (!Serial);

  delay(1000);

#if defined(ARDUINO_ARCH_MBED)
  Serial.print("Starting SD Card CardInfo on MBED ");
#else
  Serial.print("Starting SD Card CardInfo on ");
#endif
  
  Serial.println(BOARD_NAME);
  Serial.println(RP2040_SD_VERSION);
  
  Serial.print("Initializing SD card with SS = ");  Serial.println(PIN_SD_SS);
  Serial.print("SCK = ");   Serial.println(PIN_SD_SCK);
  Serial.print("MOSI = ");  Serial.println(PIN_SD_MOSI);
  Serial.print("MISO = ");  Serial.println(PIN_SD_MISO);

  // we'll use the initialization code from the utility libraries
  // since we're just testing if the card is working!
  if (!card.init(SPI_HALF_SPEED, chipSelect)) 
  {
    Serial.println("initialization failed. Things to check:");
    Serial.println("* is a card inserted?");
    Serial.println("* is your wiring correct?");
    Serial.println("* did you change the chipSelect pin to match your shield or module?");
    while (1);
  } 
  else 
  {
    Serial.println("Wiring is correct and a card is present.");
  }

  // print the type of card
  Serial.println();
  Serial.print("Card type:         ");
  
  switch (card.type()) 
  {
    case SD_CARD_TYPE_SD1:
      Serial.println("SD1");
      break;
    case SD_CARD_TYPE_SD2:
      Serial.println("SD2");
      break;
    case SD_CARD_TYPE_SDHC:
      Serial.println("SDHC");
      break;
    default:
      Serial.println("Unknown");
  }

  // Now we will try to open the 'volume'/'partition' - it should be FAT16 or FAT32
  if (!volume.init(card)) 
  {
    Serial.println("Could not find FAT16/FAT32 partition.\nMake sure you've formatted the card");
    while (1);
  }

  Serial.print("Clusters:          ");
  Serial.println(volume.clusterCount());
  Serial.print("Blocks x Cluster:  ");
  Serial.println(volume.blocksPerCluster());

  Serial.print("Total Blocks:      ");
  Serial.println(volume.blocksPerCluster() * volume.clusterCount());
  Serial.println();

  // print the type and size of the first FAT-type volume
  uint32_t volumesize;
  Serial.print("Volume type is:    FAT");
  Serial.println(volume.fatType(), DEC);

  volumesize = volume.blocksPerCluster();    // clusters are collections of blocks
  volumesize *= volume.clusterCount();       // we'll have a lot of clusters
  volumesize /= 2;                           // SD card blocks are always 512 bytes (2 blocks are 1KB)
  Serial.print("Volume size (Kb):  ");
  Serial.println(volumesize);
  Serial.print("Volume size (Mb):  ");
  volumesize /= 1024;
  Serial.println(volumesize);
  Serial.print("Volume size (Gb):  ");
  Serial.println((float)volumesize / 1024.0);

  if (!SD.begin(PIN_SD_SS)) 
  {
    Serial.println("Initialization failed!");
    return;
  }
  
  Serial.println("Initialization done.");

  Serial.println("\nFiles found on the card (name, date and size in bytes): ");

  root = SD.open("/");

  printDirectory(root, 0);
}

void loop() 
{
}

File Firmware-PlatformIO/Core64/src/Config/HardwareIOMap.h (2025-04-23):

/*
	PURPOSE: Define/assign/log the hardware version scheme and number.
				Map out all of the IO for each version of the Core 64 hardware.
         		The Hardware_IO_Map.cpp file detects and sets the hardware version.
	SETUP: Manually update the field assigned as VERSION	
*/


#ifndef HARDWARE_IO_MAP_H
	#define HARDWARE_IO_MAP_H
	#include <stdint.h>
	#include <stdbool.h>

	/*  HARDWARE VERSION SCHEME (see https://semver.org/)
			Given a version number MAJOR.MINOR.PATCH, increment the
				MAJOR version when you make incompatible API changes,
				MINOR version when you add functionality in a backwards compatible manner, and
				PATCH version when you make backwards compatible bug fixes.
			Hardware version is stored in Board ID EEPROM on the Logic Board.
	*/
	/**************************************** CORE64 HARDWARE VERSION TABLE *******************************************
	| VERSION |  DATE      | MCU  | DESCRIPTION                                                                       |
	-------------------------------------------------------------------------------------------------------------------
	|  0.1.0  | 2019-08-09 | TLC  | Single board prototype development
	|  0.1.5  | 2020-02-22 | TLC  | Single board, reworked board fixes, prototype development
	|  0.2.0  | 2020-03-16 | TLC  | Single board, design updated to match v0.1.5, theoretically (not produced)
	|  0.3.0  | 2020-05-30 | TLC  | Dual board, hardware version detection for 0.2.x (includes v0.1.x) and v0.3.x
	|  0.3.1  | 2020-05-30 | TLC  | Two voltage regulators, 5V0 and 3V3, powered from common switch point
	|  0.4.0  | 2020-11-28 | T32  | Blue LB, Yellow CB with Plane 4 set, as-built bring-up
	|  0.5.0  | 2021-03-20 | T32  | Triple-board, Black LB/CB/CM
	|  0.6.0  | 2021-12-25 | T32  | Triple-board, Black LB/CB/CM
	|  0.7.x  | 2023-03-19 | Pico | Triple-board, White LB/CB/CM, and reworked LB 0.7.1
	|         |            | 
	-----------------------------------------------------------------------------------------------------------------*/
	/**************************************** CORE64c HARDWARE VERSION TABLE ******************************************
	| VERSION |  DATE      | MCU  | DESCRIPTION                                                                       |
	------------------------------------------------------------------------------------------------------------------
	|  0.1.0  | 2021-05-28 | Pico | First layout, abandoned, not prototyped
	|  0.2.0  | 2021-06-04 | Pico | White Board, as prototyped
	|  0.2.1  | 2022-04-13 | Pico | White Board, air wired fixes to shift register circuit (pin 9 to 14 daisy chained, pin 12 all common)
	|  0.3.0  | 2022-05-25 | Pico | White Board, as prototyped
	|  0.4.0  | 2022-06-11 | Pico | White Board, multiple production batches
	|         |            | 
	----------------------------------------------------------------------------------------------------------*/
	extern uint8_t HardwareVersionMajor; // See EEPROM_HAL
	extern uint8_t HardwareVersionMinor; // See EEPROM_HAL
	extern uint8_t HardwareVersionPatch; // See EEPROM_HAL
	static bool PicoWTested;	// See Analog_Input_Test
	static bool PicoWPresent;	// See Analog_Input_Test

/*
	CARRIER BOARD Type and MCU TYPE
	ex: Teensy 3.2 with MK20DX256, Raspberry Pi Pico with RP2040
	MCU selected at compile time based on user selected build environment and per compiler configuration. Use 
	#define because there is no need to use a RAM variable. The #define will specify what can be compiled in
	because there is no reason to compile in potentially incompatible MCU-specific functions.
	Reference: https://arduino.stackexchange.com/questions/21137/arduino-how-to-get-the-board-type-in-code
*/
	#if defined(TEENSYDUINO) 
		#if defined(__MK20DX256__) 
			#define CARRIER_BOARD "Teensy 3.2" // and Teensy 3.1 (obsolete)
			#define CARRIER_BOARD_CORE64_TEENSY_32
			#define MCU "MK20DX256"
			#define MCU_TYPE_MK20DX256_TEENSY_32
		#elif defined(__MKL26Z64__)       
	        #define CARRIER_BOARD "Teensy LC"
			#define CARRIER_BOARD_CORE64_TEENSY_LC
			#define MCU "MKL26Z64"
			#define MCU_TYPE_MKL26Z64_TEENSY_LC
		#endif
	#else
		#if defined(ARDUINO_ARCH_RP2040)       
			#define CARRIER_BOARD "Raspberry Pi Pico RP2040 MCU"
			#define CARRIER_BOARD_RASPBERRY_PI_PICO
			#define MCU "RP2040"
			#define MCU_TYPE_RP2040
		#endif
	#endif
	// Display MCU and carrier board name which is being compiled for:
	#pragma message ( "C++ Preprocessor identified CARRIER BOARD and MCU type: " )
	#ifdef CARRIER_BOARD
		#pragma message ( CARRIER_BOARD )
		#pragma message ( MCU )
	#else
		#error ( "Unsupported board. In bottom of editing window choose 'env:pico' or 'env:teensy31'." )
	#endif
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

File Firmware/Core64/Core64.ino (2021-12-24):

/*
    ____                __   _  _   
   / ___|___  _ __ ___ / /_ | || |  
  | |   / _ \| '__/ _ \ '_ \| || |_ 
  | |__| (_) | | |  __/ (_) |__   _|
   \____\___/|_|  \___|\___/   |_|  
                                  
  Core64 Interactive Core Memory - Project website: www.Core64.io
  2019-2021 Concept and Design by Andy Geppert of www.MachineIdeas.com
  Hardware version and details in HardwareIOMap.h
  This source code: https://www.github.com/ageppert/Core64
  
  DEVELOPMENT ENVIRONMENT
    Arduino IDE 1.8.9                                       https://www.arduino.cc/en/Main/Software
    Core64 requires TEENSYDUINO LOADER 1.53                 https://www.pjrc.com/teensy/td_download.html
      Select ALL additional libraries during installation of Teensyduino Loader and associate with the Arduino 1.8.9 installation.
    Core64c does not use the TEENSYDUINO LOADER AT ALL

  LIBRARY DEPENDENCIES
    USER MUST INSTALL MANUALLY IN ARDUINO
      Arduino > Tools > Manage Libraries > Install
      The libraries should end up being in your "Libraries" folder in your default Arduino Sketchbook location.
      Adafruit_SSD1306                              2.2.0   by Adafruit for Monochrome OLED 128x64 and 128x32
      Adafruit_GFX_Library                          1.10.6  by Adafruit
      Adafruit_BusIO                                1.3.1   by Adafruit, testeing 1.9.3 with RP2040 support
    TEENSYDUINO LOADER 1.53 INSTALLED THESE
      Wire                                          1.0     in Arduino1.8.9.app/Contents/Java/hardware/teensy/avr/libraries/Wire/
      FastLED                                       3.3.3   in Arduino1.8.9.app/Contents/Java/hardware/teensy/avr/libraries/FastLED by Daniel Garcia
      SPI                                           1.0     in Arduino1.8.9.app/Contents/Java/hardware/teensy/avr/libraries/SPI/
    INCLUDED IN THIS PROJECT'S SRC DIRECTORY
      Si7210
      LTR329
      CommandLine                                   2.1.0   by Bas Stottelaar (MIT License) https://github.com/basilfx/Arduino-CommandLine 
    OPTIONAL STUFF IF YOU ADD THIS HARDWARE
      Adafruit ILI9341 Library                      1.5.6   by Adafruit
      Adafruit_SSD1327                              1.0.0   by Adafruit for Monochrome OLED 128x128
      Adafruit_SSD1351                              1.2.7   by Adafruit for Color OLED 1.27" and 1.5" in the Adafruit shop
      SdFat - Adafruit Fork                         1.2.3   by Bill Greiman (fork of SdFat)
      SparkFun Ambient Light Sensor Arduino Library 1.0.3   by Ellas Santistevan
      TeensyView                                    1.1.0   by Sparkfun for monochrome OLED 128x32 in the Sparkfun store
 */

#include <stdint.h>
#include <stdbool.h>

#include "HardwareIOMap.h"
#include "Heart_Beat.h"
#include "Serial_Debug.h"
#include "LED_Array_HAL.h"
#include "Neon_Pixel_HAL.h"
#include "OLED_Screen.h"
#include "Analog_Input_Test.h"
#include "Buttons_HAL.h"
#include "Core_HAL.h"
#include "EEPROM_HAL.h"
#include "I2C_Manager.h"
#include "SD_Card_Manager.h"
#include "Ambient_Light_Sensor.h"
#include "src/CommandLine/CommandLine.h"
#include "Core_Driver.h"
#include "Test_Functions.h"

// Command Line Stuff:
  #if defined BOARD_CORE64_TEENSY_32
    #define PROMPT "Core64> "
  #elif defined BOARD_CORE64C_RASPI_PICO
    #define PROMPT "Core64c: "
  #else
    #define PROMPT "unknown: "
  #endif
  int StreamEnable = 0;
  CommandLine commandLine(Serial, PROMPT);        // CommandLine instance.

// #define DEBUG 1

static uint32_t SerialNumber = 0;          // Default value is 0 and should be non-zero if the Serial Number is valid.
static bool TopLevelModeChanged = false;
enum TopLevelMode                  // Top Level Mode State Machine
{
  MODE_STARTUP = 0,                //   0 Start-up
  MODE_SCROLLING_TEXT,             //   1 Scrolling text at power on
  MODE_CORE_FLUX_DETECTOR,         //   2 Testing all cores and displaying core state
  MODE_MONOCHROME_DRAW,            //   3 Test LED Driver with binary values
  MODE_LED_TEST_ALL_BINARY,        //   4 Test LED Driver with binary values
  MODE_LED_TEST_ONE_STRING,        //   5 Testing LED Driver
  MODE_LED_TEST_ONE_MATRIX_MONO,   //   6 Testing LED Driver with matrix array and monochrome color
  MODE_LED_TEST_ONE_MATRIX_COLOR,  //   7 Testing LED Driver with matrix array and multi-color symbols
  MODE_TEST_EEPROM,                //   8
  MODE_LED_TEST_ALL_COLOR,         //   9 Test LED Driver with all pixels and all colors
  MODE_CORE_TOGGLE_BIT,            //  10 Test one core with one function
  MODE_CORE_TEST_ONE,              //  11 Testing core #coreToTest and displaying core state
  MODE_CORE_TEST_MANY,             //  12 Testing multiple cores and displaying core state
  MODE_HALL_TEST,                  //  13 Testing hall switch and sensor response
  MODE_LOOPBACK_TEST,              //  14 For the manufacturing test fixture, test unused IO pins
  MODE_LAST,                       //  15 last one, return to 0.
} ;
static uint8_t TopLevelModeDefault = MODE_STARTUP;
static uint8_t TopLevelMode = TopLevelModeDefault;
uint8_t value = 0;
uint8_t a = 0;

/*                      
                          *********************
                          ***     Setup     ***
                          *********************
*/
void setup() {
  HeartBeatSetup();
  #if defined BOARD_CORE64_TEENSY_32
    LED_Array_Init();
    SerialDebugSetup();
      Serial.begin(SERIAL_PORT_SPEED);  // Need to move this serial stuff into the Serial_Debug.c file out of here!
      LED_Array_Test_Pixel_Matrix_Color();
    EEPROM_Setup();
    OLEDScreenSetup();
    I2CManagerSetup();
      delay(3000);
    I2CManagerBusScan();
    // TO DO: Most of this setup should occur after the hardware version is determined, so setup is configured appropriately
    Buttons_Setup();
    CoreSetup();
    SDCardSetup();
    AmbientLightSetup();
    Neon_Pixel_Array_Init();
  #elif defined BOARD_CORE64C_RASPI_PICO
    EEPROM_Setup();
    I2CManagerSetup();
      delay(3000);
    I2CManagerBusScan();
    OLEDScreenSetup();
    Buttons_Setup();
  #endif
    DetectHardwareVersion();
    CommandLineSetup();
    AnalogSetup();
    AnalogUpdate();
}

/*                      
                          *********************
                          ***   MAIN LOOP   ***
                          *********************
*/
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

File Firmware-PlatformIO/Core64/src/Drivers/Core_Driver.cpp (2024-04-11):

#include <stdint.h>
#include <stdbool.h>

/*
#if (ARDUINO >= 100)
#include <Arduino.h>
#else
#include <WProgram.h>
#endif
*/

#include "Config/HardwareIOMap.h"

#include "Drivers/Core_Driver.h"
#include "SubSystems/I2C_Manager.h"
#include "Hal/EEPROM_HAL.h"
#include "SubSystems/Serial_Port.h"
#include "Hal/Debug_Pins_HAL.h"

enum CorePatternArrangement
{
      CORE_ARRANGEMENT_UNDEFINED = 0,
/*   If the outer corners of the core plane cores are arranged like this
      / \
      \ /
      Use CORE_ARRANGEMENT_NORMAL (Default)                                       
*/
      CORE_ARRANGEMENT_NORMAL = 1,
/*   If the outer corners of the core plane cores are arranged like this:
      \ /
      / \
      Use CORE_ARRANGEMENT_OPPOSITE
*/
      CORE_ARRANGEMENT_OPPOSITE = 2,
};
static uint8_t CorePatternArrangement = CORE_ARRANGEMENT_NORMAL;  // Default Core Pattern Arrangement. Updateable from serial port and EEPROM.

static uint8_t CorePlane = 1;           // Default Core Plane if it is not specified by the user application.
#ifdef MULTIPLE_CORE_PLANES_ENABLED
  const bool CorePlaneAddr[9][3] = {
    { 0,0,0 },  // not used
    { 0,0,0 },  // Plane 1 (MSB to LSB)
    { 0,0,1 },  // Plane 2
    { 0,1,0 },  // Plane 3
    { 0,1,1 },  // Plane 4
    { 1,0,0 },  // Plane 5
    { 1,0,1 },  // Plane 6
    { 1,1,0 },  // Plane 7
    { 1,1,1 }   // Plane 8     
  };
#endif


#if defined  MCU_TYPE_MK20DX256_TEENSY_32
  // Array from 1-20 with MCU pin # associated to verbose transistor drive line name. Ex: PIN_MATRIX_DRIVE_Q1P
  // Array position number 0 is not used in the matrix pin numbering
  // Matrix Drive Line array position :         0, 1, 2, 3, 4, 5, 6, 7, 8, 9,10,11,12,13,14,15,16,17,18,19,20,21,22,23,24,25,26,27,28,29,30,31,32,33
  // Look out for these!              :                                                               *  *  *
  // V0.3 MCU PIN #                   :       N/A, 1, 2, 3, 4, 5, 6, 7, 8, 9,10,11,12,13,14,15,16,17, -, -,20,21,22
  // V0.4 MCU PIN #                   :       N/A, -, 1, 2, 3, 4, 5, 6, 7, 8, -, -, -, -, -, -, 9,10, -, -, -, -, -, -,11,12,13,14,15,16,17,20,21,22
  static uint8_t MatrixDrivePinNumber[34] = {
    0,
    0,
    PIN_MATRIX_DRIVE_Q1P ,
    PIN_MATRIX_DRIVE_Q1N ,
    PIN_MATRIX_DRIVE_Q2P ,
    PIN_MATRIX_DRIVE_Q2N ,
    PIN_MATRIX_DRIVE_Q3P ,
    PIN_MATRIX_DRIVE_Q3N ,
    PIN_MATRIX_DRIVE_Q4P ,
    PIN_MATRIX_DRIVE_Q4N ,
    0,
    0,
    0,
    0,
    0,
    0,
    PIN_MATRIX_DRIVE_Q5P ,
    PIN_MATRIX_DRIVE_Q5N ,
    0,
    0,
    0,
    0,
    0,
    0,
    PIN_MATRIX_DRIVE_Q6P ,
    PIN_MATRIX_DRIVE_Q6N ,
    PIN_MATRIX_DRIVE_Q7P ,
    PIN_MATRIX_DRIVE_Q7N ,
    PIN_MATRIX_DRIVE_Q8P ,
    PIN_MATRIX_DRIVE_Q8N ,
    PIN_MATRIX_DRIVE_Q9P ,
    PIN_MATRIX_DRIVE_Q9N ,
    PIN_MATRIX_DRIVE_Q10P,
    PIN_MATRIX_DRIVE_Q10N
  };

  // All QxN transistors are Active High.
  // All QxP transistors are Active Low.

  // V0.4 hardware (direct MCU pin control)
  // Look up the drive line number by knowing where it is in the array by it's own number.
  // In other words, the pin # has to be the same as the array position.
  // Array needs to be as big as the largest used pin number.
  // Ex:
  //                             array position:  0, 1, 2, 3, 4, 5, 6, 7, 8, 9,10,11,12,13,14,15,16,17,18,19,20,21,22,23,24,25,26,27,28,29,30,31,32,33
  // V0.4 MCU PIN #              usable pins   :  x, x, 1, 2, 3, 4, 5, 6, 7, 8, x, x, x, x, x, x, 9,10, x, x, x, x, x, x,11,12,13,14,15,16,17,20,21,22
  // MCU output pins are set to these states to correspond to activation of the transistor needed to achieve on/off state.
  const bool MatrixDrivePinInactiveState[34] =  { 0, 0, 1, 0, 1, 0, 1, 0, 1, 0, 0, 0, 0, 0, 0, 0, 1, 0, 0, 0, 0, 0, 0, 0, 1, 0, 1, 0, 1, 0, 1, 0, 1, 0}; // logic level to turn off transistor
  const bool MatrixDrivePinActiveState[34]   =  { 0, 0, 0, 1, 0, 1, 0, 1, 0, 1, 0, 0, 0, 0, 0, 0, 0, 1, 0, 0, 0, 0, 0, 0, 0, 1, 0, 1, 0, 1, 0, 1, 0, 1}; // logic level to turn on transistor


  // MCU output pin is set to these states to correspond to activation of the transistor needed to achieve active/inactive state.
  #define WRITE_ENABLE_ACTIVE   1 // logic level to turn on transistor
  #define WRITE_ENABLE_INACTIVE 0 // logic level to turn off transistor

  // Given a Core Memory Matrix Row 0 to 7 the array below specifies which 2 pins connected to transistors are required to set the row.
  // CMM front (user) view is with Row 0 on top, 7 on bottom.
  // Each row of the array corresponds to rows 0 to 7 of the CMM.
  // Each row is sequence of 2 transitors, first one connects to top four rows and second one connects to the bottom four rows.
  /* 
  The original assumption of current going left to right in a row does not work because the cores
  are not all placed in the same orientation. The cores alternate back and forth in a row, and in 
  columns, to make the circuit simpler. A new row set and clear array are required which take into 
  account that every other bit needs to have the current direction reversed in order to compensate 
  if all of the cores are to be physically addressed in an orderly sequence. 
  */
  // V0.1.x and V0.2.x and V0.4.x hardware (direct MCU pin control)

  static uint8_t CMMDSetRowByBit[][2] = {

    { PIN_MATRIX_DRIVE_Q7P , PIN_MATRIX_DRIVE_Q9N  },  // Bit 32    ROW 4 P/N swapped from ROW 0
    { PIN_MATRIX_DRIVE_Q7N , PIN_MATRIX_DRIVE_Q9P  },  // Bit 33    ROW 4
    { PIN_MATRIX_DRIVE_Q7P , PIN_MATRIX_DRIVE_Q9N  },  // Bit 34    ROW 4
    { PIN_MATRIX_DRIVE_Q7N , PIN_MATRIX_DRIVE_Q9P  },  // Bit 35    ROW 4
    { PIN_MATRIX_DRIVE_Q7P , PIN_MATRIX_DRIVE_Q9N  },  // Bit 36    ROW 4
    { PIN_MATRIX_DRIVE_Q7N , PIN_MATRIX_DRIVE_Q9P  },  // Bit 37    ROW 4
    { PIN_MATRIX_DRIVE_Q7P , PIN_MATRIX_DRIVE_Q9N  },  // Bit 38    ROW 4
    { PIN_MATRIX_DRIVE_Q7N , PIN_MATRIX_DRIVE_Q9P  },  // Bit 39    ROW 4

    { PIN_MATRIX_DRIVE_Q7N , PIN_MATRIX_DRIVE_Q10P },  // Bit 40    ROW 5 P/N swapped from ROW 1
    { PIN_MATRIX_DRIVE_Q7P , PIN_MATRIX_DRIVE_Q10N },  // Bit 41    ROW 5
    { PIN_MATRIX_DRIVE_Q7N , PIN_MATRIX_DRIVE_Q10P },  // Bit 42    ROW 5
    { PIN_MATRIX_DRIVE_Q7P , PIN_MATRIX_DRIVE_Q10N },  // Bit 43    ROW 5
    { PIN_MATRIX_DRIVE_Q7N , PIN_MATRIX_DRIVE_Q10P },  // Bit 44    ROW 5
    { PIN_MATRIX_DRIVE_Q7P , PIN_MATRIX_DRIVE_Q10N },  // Bit 45    ROW 5
    { PIN_MATRIX_DRIVE_Q7N , PIN_MATRIX_DRIVE_Q10P },  // Bit 46    ROW 5
    { PIN_MATRIX_DRIVE_Q7P , PIN_MATRIX_DRIVE_Q10N },  // Bit 47    ROW 5
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

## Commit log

2021-04-28 Add schematics
2021-05-11 Swap Y0-3 and Y4-7 drive current direction to enable use of cores aligned opposite from standard kit configuration
    [Core_Driver.cpp, HardwareIOMap.h]
2021-08-11 Update EEPROM read state to show external EEPROM values instead of internal Teensy emulated EEPROM
2021-09-06 Detect compile-time hardware Teensy 3.2 or RasPi Pico and compile for target, Pico mode has a heartbeat and that is it
2021-09-06 Enable Core64c RasPi Pico support for I2C, external EEPROM, hardware version detect. Enable CLI with help, info, mode, splash commands
2021-09-28 Enable hall switches and hall sensors both functioning together with #defines for Core64 only
2021-09-29 Hall sensors and switches working in Core64c Pico config, clean and organize hardware #defines
2021-09-29 Enable Mode 13 Hall Test and add OLED support for Core64c, required Adafruit_BusIO library update from 1.3.1 to 1.9.3 and OLED CLK during/after reduction back to 100kHz
2021-10-01 fwv0.5.5 - Display Voltage Input (USB or Bat.) for Core64 V0.5.0 and Core64c V0.2.0
2021-12-21 Add mechanical folder, teensy socket jig, diffuser grid round and square
    [Alignment Jig Sockets Teensy3.2 on LB V0.5-0.6 (V2).stl, Diffuser Grid V0.2 Round 4mm Pixel Holes.stl, Diffuser Grid V0.2 Square 4mm Pixel Holes.stl]
2021-12-24 Enable Core64 V0.6.0 for bring-up. Maintain backwards compatibility. Enable hardware V0.6.0 config, disable hall switch by default to avoid HS#4 from being active in test fixture with loopback wired 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
    [Buttons_HAL.cpp, Command_Line_Handler.ino, Core64.ino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]
2021-12-25 Print serial number zero-padded to 6 digits, remove manual date/time from firmware version suffix
2022-01-09 Add V0.6 schematics and image for landing page readme
2022-02-12 Create Core64 Firmware-PlatformIO project folder, split files and organized into sub-directories.
    | 0.7.0 | 2022-01-02 | Move from Arduino to PlatformIO, split files into sub-directories, broke Core64c (I2C1) compatibility.
    | 0.7.1 | 2022-01-22 | Fixing I2C issues so Core64 and Core64c both work.
    | 0.7.2 | 2022-01-30 | Move Commandline Handler and Mode Manager out to their own files, outside of main.c
    | 0.7.3 | 2022-02-04 | Move Serial setup outside of main.c, add debug level to commandline.
    [Ambient_Light_Sensor.cpp, Buttons_HAL.cpp, Core_Driver.cpp]
2022-02-12 FWV0.7.4: Organize TopLevelMode list, placeholder GAUSS menu.
    Fix color symbol display in LED_Array_Matrix_Color_Display(), bug was only showing monochrome.
    Add TopLevelModePrevious variable and display.
    Re-organize TopLevelMode numbers.
    Add GUASS menu placeholder and character symbol.
    Add gauss command to jump to GAUSS menu.
    Split Firmware_Version.h out of HardwareIOMap.h
    Increase commandline count allowed from 8 to 25.
    [HardwareIOMap.h, LED_Array_HAL.cpp, Mode_Manager.cpp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]
2022-02-14 FWV0.7.5: Implement DGAUSS MENU, draw mode UI improved, organized sub-menu category modes.
    Add enter/exit DGAUSS menu with M button. Sub-menu graphics are not implemented yet.
    Add + and - soft buttons cycle through modes in sub-menu, globally. Unless [optionally] used in the mode.
    Add S soft button jumps to settings sub-menu, globally.
    Improve Draw mode UI, Screen clear with S button, leaves M reserved for DGAUSS MENU.
    Expand CLI help menu to explain buttons.
    Increase Hall sensor button sensitivity.
    Bug fix: ScreenPixelPositionBinaryLUT was backwards for custom Core64 LED Matrix.
    [Buttons_HAL.cpp, LED_Array_HAL.cpp]
2022-03-07 FWV0.7.6: Add array of string descriptions for all modes.
    Display description of mode when changed.
    List all modes when queried with 'mode' via CLI.
    Add 30s timeout for DGAUSS menu.
    Disable -,+,S detection in hall sensor test mode
    Change order of DGAUSS menu ...special, settings.
    Bug fix: Rainbow demo works again with delay removed.
    [LED_Array_HAL.cpp, Mode_Manager.cpp]
2022-03-13 FWV0.7.7: Placeholders for all sub-menus with symbols and end of each sub-list wrap around to beginning of sub-list.
    Move all setup() stuff to Start-Up Modes.
    Add Core, 64, hysteresis loop, intro start-up sequence, and make sure it is displayed for at least 3 seconds.
    Split some of the modes in the Mode Manager State Machine out into their own files, in the appropriate sub folders.
    Reset Mode Change Flag to false the first time it is checked. One time use.
    Create and activate all sub-menus with symbols, and end-of-list modes to jump back to beginning of list.
    Updated firmware architecture document WIP.
    Max and Min loop time identifies which mode # caused the max or min time.
    BUG FIX: Mode #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
    [Apps_Sub_Menu.cpp, Games_Sub_Menu.cpp, LED_Array_HAL.cpp]
2022-03-18 FWV0.7.8: Add Game of Snake!
    Sub-menus updated to only disable SET button. Keep + and - to select from the list.
    Port in Game of Snake!
    Add W and L for win and lose in game snake.
    Add time-out from game mode if the cores are not changed or game is not re-started within 30s. Re-use/adapt MenuTimeOut in Mode_Manager.
    In Game Sub Menu use -/+ to cycle through the available choices, choose with S.
2022-03-28 FWV0.7.9: Refine start-up mode sequence, I2C, hall sensor button set-up.
    Add Quick Start Guide and Basic User Manual docs.
2022-04-05 FWV0.7.10-Update I2C interactions to enable Core64c to scroll text and update OLED display.
    Disable NeonPixels by default for both Core64 and Core64c.
    Disable some calls to in Core64c to prevent suspected MBED Core Crashes: Buttons_Setup(), OLEDScreenUpdate(), ButtonState(1,0).
    Testing pico platform V1.6.0
    [HardwareIOMap.h, Mode_Manager.cpp, OLED_Screen.cpp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]
2022-04-07 FWV0.7.11: Update Pico code so I2C1 port works with OLED, Hall Sensors, EEPROM.
2022-04-11 FWV 0.7.12: Update Pico code so all multicolor LED Matrix functions work.
    Enable color in DGAUSS Menu Core64c.
    Enable color in SNAKE game Core64c.
    Bug Fix: Change upload port in platform.io to /dev/cu.usbmodem14201 for easier upload with reset button.
    [LED_Array_HAL.cpp]
2022-04-18 FWV 0.7.13: Core64c, Pico, implement core driver!
2022-05-08 FWV 0.7.16: Core64c, Pico, SPI and SD Card tested, all spare GPIO test mode, hall switch test, use built-in Pico VSYS/3 to read 5V0 and GPIO24 for VBUS sense.
2022-08-07 FWV 0.7.19: Core64 LB disable SD Card by default so heartbeat runs, expand hardware version checks to major and minor numbers
    [Diffuser Grid V0.2 Square 4mm Pixel Holes.stl, Diffuser Grid V0.9 Square 6.75mm centers.stl]
2022-09-04 FWV 0.7.20: Add Core64c, update LED heartbeat and Analog Input VSYS for compatibility with optional Pico W. Add placeholder MODE_MANUFACTURING_EEPROM_FACTORY_WRITE.
2022-09-17 FWV0.7.21: Add basic game of Pong, protect for LED Matrix Array overload
2022-12-21 Add Core64c Case A and B stl files
2022-12-27 Add Assembly Guide, Firmware Update Guide, Readme
    Remove source version of files and replace with PDFs.
2023-02-20 Core64, add core # to MODE_CORE_TOGGLE_BITS_WITH_3V3_READ analog voltage data stream, add read ANA7 (A12) connected above CAE FET with modified LB
2023-04-13 Core64, add compatibility for Core64 V0.7+ Pico Version, remove unused Detect_Board file
2023-04-24 Add Core64 v0.8 and Core64c v0.4 schematics and images
2023-05-22 Add LED Array QC-Test folder and files
2023-06-15 LED QC Test Procedure: Clarify three test connection points on PCB.
2023-09-05 FWV0.7.28: Corrected mistakes when I merged to master. Should now behave like 0.7.27.
    [LED_Array_HAL.cpp, Mode_Manager.cpp]
2023-09-08 FWV0.8.0: Core16 support introduction, WIP. Most [enough] LED functions working with Core16. In the midst of Core Driver updates for Core16.
2023-09-12 FWV0.8.1: Core16 LED and Core Matrix working in most modes
2023-09-16 FWV0.8.3: Core16 tested all hardware functions. Add debug pin 1 and 2 for Core16 HWV0.1.0 and HWV0.2.0. Move LED Array Init after EEPROM Board ID read.
2023-10-22 FWV0.8.5: Core16 WIP test fixture mods, can program S/Ns 300006-300105. Add commands to set start and end cores to test.
    [Debug_Pins_HAL.cpp, EEPROM_HAL.cpp, FastLED_Config.h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]
2023-12-03 FWV0.8.9: All Core Boards, display flux detection menu symbol, disable all hall sensors in flux detector mode. Update to work with Teensy-based Core64s.
2023-12-11 FWV0.8.10: All ICM (Interactive Core Memory) Kits, display the present mode and instructions on I2C SAO OLED.
2024-04-11 FWV0.8.10: All ICM (Interactive Core Memory) Kits, display voltage on OLED in all modes, update factory setting mode, extend OutputToSerialShiftRegister, enable and test Pico Spare SR EFGH.
2024-04-27 FWV0.8.11: All ICM (Interactive Core Memory) Kits, add option to drive SPI Color OLED 1.5 inch from https://www.adafruit.com/product/1431. Stay in scrolling demo if Neon Pixels enabled. Core64 Teensy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
2024-08-25 FWV 0.8.12: LED Default and adjustable brightness and platform/library/factory config updates.
    Summer 2024 LED Arrays are too bright, need to reduce starting brightness
    Core64 and Core64c default brightness reduced with the Led Matrix V1.3 being too bright (200->125).
    Update to latest versions of platform, SSD1306, BusIO and manually include pgmspace.h in SSD1306 for MBP M1 fresh install compatibility.
    Update factory reset config details for fresh batches of Core64 and Core64c.
    [EEPROM_HAL.cpp]
2024-09-12 Add core memory demo frame STLs
    [Core Memory Demo - Large Plastic Core.stl, Core Memory Demo Frame - TOP.stl]
2025-01-14 FWV0.8.14: Update factory config values Core64 HWV0.8.4.
    Update config to use latest libraries for BusIO and Adafruit SSD1306 with Teensy builds.
2025-04-23 Change to FastLED library to remove LED glitches. Enable optional MIDI SAO support.
    [App_Midi.cpp, HardwareIOMap.h, LED_Array_HAL.cpp]
2026-08-15 Update Core64 Assembly Guide to Rev C

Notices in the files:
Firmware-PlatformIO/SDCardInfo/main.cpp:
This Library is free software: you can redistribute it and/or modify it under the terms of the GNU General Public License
